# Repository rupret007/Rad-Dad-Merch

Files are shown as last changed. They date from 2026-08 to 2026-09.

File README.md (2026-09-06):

# Rad Dad Merch

Canonical home for Rad Dad physical merchandise. History imported from `rupret007/Rad-Dad-QR-Merch` at `b001fdd`. That repo stays as backup.

<p align="center"><strong>REAL DETAILS. LOUD BAND. ONE SCAN.</strong></p>

Rad Dad QR Merch turns familiar music and computer hardware into durable,
one-color punk-rock keepsakes. The collection includes an authentic micro
compact cassette, 3.5-inch floppy disk, mini VHS cassette, and the deliberately
ridiculous Trailer Swift desk collectible.

**V9 is the recommended production release.** It keeps the successful size,
keyring, and QR-fit decisions from earlier releases while restoring or deepening
the physical details that make each object immediately recognizable.

The models remain one-color prints. The interaction layer is a separate
1-inch QR sticker that opens:

```text
https://raddadband.com/qr/
```

> [!IMPORTANT]
> V9 does not enlarge the products. External envelopes, integrated keyring
> dimensions, 6 mm media-keychain bores, and the 26-27 mm protected QR landings
> stay unchanged. Authenticity improvements are contained within those proven
> boundaries.

## Start here

| I want to... | Use this |
|---|---|
| Download the complete release | [`release/v9/Rad_Dad_Retro_Riot_v9_Authenticity_QR_Print_Pack.zip`](release/v9/Rad_Dad_Retro_Riot_v9_Authenticity_QR_Print_Pack.zip) |
| Preview the current cassette, floppy, and VHS together | [Current Three digital PETG material study](docs/previews/Rad_Dad_Current_Three_PETG_Material_Study.png) |
| Browse or hold those digital studies | `python3 tools/serve_digital_merch.py` then open `/catalog` |
| Check a cart change after a connection problem | Use **Review current hold cart**; see [cart updates and recovery](docs/DIGITAL_CART.md) |
| Recover when another tab changed the cart before confirmation | Review current quantities, then confirm again; see [review-bound holds](docs/DIGITAL_HOLD_REVIEW.md) |
| Reopen or withdraw a digital hold | Open **Your holds** at `/holds` in the same browser session; see [digital holds](docs/DIGITAL_HOLDS.md) |
| Print the current cassette, floppy, and VHS together | [`release/v9/3mf/Rad_Dad_Retro_Riot_v9_CURRENT_THREE_CASSETTE_FLOPPY_VHS_A1_MINI_0.4_PROJECT.3mf`](release/v9/3mf/Rad_Dad_Retro_Riot_v9_CURRENT_THREE_CASSETTE_FLOPPY_VHS_A1_MINI_0.4_PROJECT.3mf) |
| Print the four models | [`release/v9/3mf/`](release/v9/3mf) or [`release/v9/stl/`](release/v9/stl) |
| Send one sticker to a professional vendor | `release/v9/guides/qr_stickers/Rad_Dad_QR_1IN_VENDOR_MASTER.svg` or its PDF master |
| Print precut Avery 6450 / OL1025 labels | `release/v9/guides/qr_stickers/Rad_Dad_QR_AVERY_6450_OL1025_63UP_US_LETTER.pdf` |
| Print a full adhesive sheet at FedEx Office | `release/v9/guides/qr_stickers/Rad_Dad_QR_FEDEX_OFFICE_FULL_SHEET_48UP_US_LETTER.pdf` |
| Print when black ink is unavailable | Official `Rad_Dad_QR_RED_*` fallback files in `release/v9/guides/qr_stickers/` |
| Understand sticker production | [QR sticker guide](docs/QR_STICKERS.md) |
| Review the retired NFC workflow | [NFC legacy notice](docs/NFC.md) |

The v9 ZIP is the canonical handoff. The paths above are the generated v9
release layout already present in this repository.

### Current Three material study

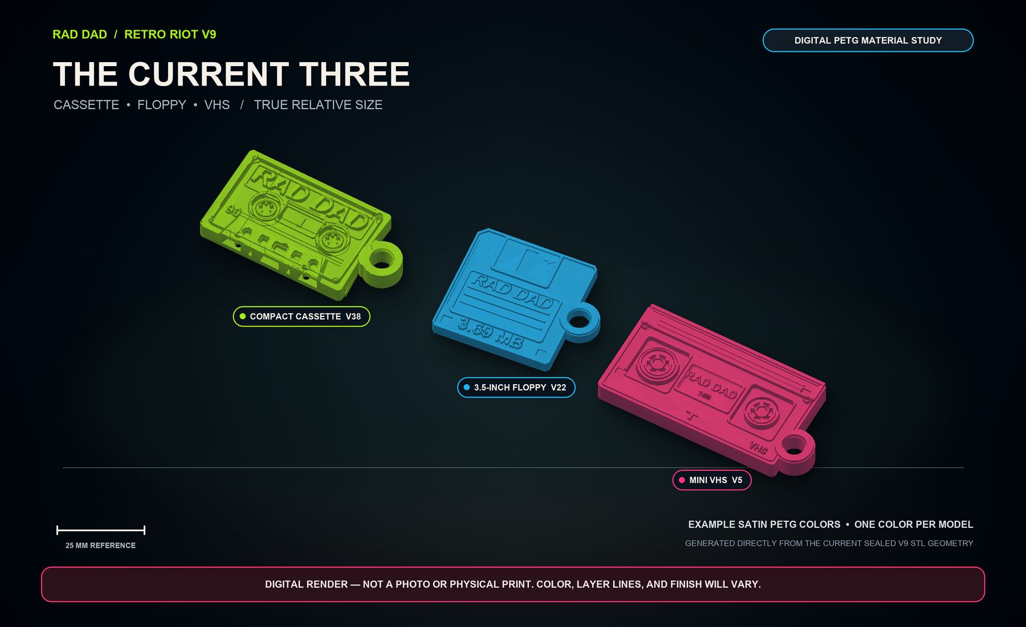
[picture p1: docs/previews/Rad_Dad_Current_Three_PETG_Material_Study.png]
Digital PETG material study of the current Rad Dad cassette, floppy, and mini VHS


This preview is generated directly from the three current sealed v9 STL files
with one shared orthographic camera, so their relative sizes remain honest.
The lime, blue, and pink surfaces are example one-color satin PETG treatments;
the image is not a photo, slicer preview, printability result, or substitute for
the physical acceptance checklist. Its source hashes, measured envelopes,
renderer identity, digital-only status, and output hash are recorded in the
[provenance file](docs/previews/Rad_Dad_Current_Three_PETG_Material_Study.json).
Regenerate or verify it with:

```bash
python3 tools/render_current_three_material_study.py
python3 tools/render_current_three_material_study.py --check
python3 tools/serve_digital_merch.py
python3 tools/verify_digital_merch.py
```

The digital merch desk turns that leftover study into a shopper catalog, cart,
and admin publish/hold path. Catalog cards crop the shared render so cassette,
floppy, and mini VHS are identifiable on a phone. Checkout cannot run until the
shopper confirms a digital hold, then it opens a session-owned receipt. It
accepts digital study requests only. It does not take payment, ship an object,
start a Bambu job, change the QR destination, or post merch. The public merch
path serves the study image and catalog copy; it does not serve STL, 3MF,
renderer, or release files. Admin stays locked until
`RAD_DAD_MERCH_ADMIN_TOKEN` is set.

**Your holds** lists this browser session's receipts, newest first. A shopper can
reopen a receipt and explicitly confirm withdrawal; the admin sees the same
withdrawn status. The original receipt stays readable. Holds live only in the
running server's memory: a server restart clears them, and clearing or losing
the session cookie removes access. See [digital holds](docs/DIGITAL_HOLDS.md)
for the flow and verification.

Cart updates show a visible result and pause further edits while pending. If a
response is lost, the browser never resends the change automatically: use
**Review current hold cart** to load the server's current quantities before
editing or requesting a hold. See [cart updates and recovery](docs/DIGITAL_CART.md).
Hold confirmation is also bound to the cart that was actually reviewed. A
changed or stale review creates no hold: the cart shows its current contents,
retains valid unsent contact/note text on that response, and requires fresh
confirmation. Empty or unavailable carts cannot submit. See
[review-bound holds](docs/DIGITAL_HOLD_REVIEW.md) for the API and recovery limits.
Digital verification uses Python 3.9+ and Node.js 18+; the JavaScript checks
use Node's standard library and require no npm packages.

## What changed in v9

### Cassette v38

Cassette v38 uses the watertight, audited v36 cassette body that produced the
successful physical reference print. Its **actual narrow tape-entry edge** is
preserved directly, including the stepped shell and asymmetric transport
apertures where a real cassette deck's head, capstan, guides, and pinch roller
engage the tape. These are not reconstructed face markings or generic slots.

Only the side-eyelet zone is moved inward to retain the later compact envelope.
The deformation is zero at the tape-entry edge, so the inherited transport
geometry remains unchanged. The proven 6 mm bore and rear QR landing are part
of the same audited body.

The shell still carries unequal tape packs, six-lobe drive hubs, center tape
window, pressure-pad cue, shell hardware, readable `RAD DAD`, `90`, and the
small `C-69` easter egg. The existing rear QR landing and compact keyring eyelet
remain unchanged.

### Floppy v22

Floppy v22 retains the developed rear hub, shutter-track, shell-seam,
write-protect, and density cues that make the underside read as a real 3.5-inch
floppy instead of a flat backing plate. The front keeps its shutter, label
hierarchy, and `RAD DAD`, while the `3.69 MB` joke is enlarged to
20.00 x 4.00 mm with heavier strokes for reliable one-color printing.

The improved marking and rear treatment stay inside the same protected 1-inch
QR landing, outside size, 4.130 mm thickness, and keyring geometry.

### VHS v5

VHS v5 strengthens the device-specific reel, tape-path, door, latch, insertion,
shell, and rear-housing cues so it reads as a VHS cassette from the front, side,
and back rather than as a stretched compact cassette.

The established rear QR landing, product envelope, and keyring geometry stay
unchanged. The restrained `T-369` detail remains part of the collection-wide
capacity joke.

### Trailer Swift v16

Trailer Swift v16 keeps the spiky punk hair, guitar, compact toy proportions,
solid display base, and readable `TRAILER SWIFT` nameplate while changing the
character's expression from angry or scary to friendly, funny, and knowingly
ridiculous. A slimmer, slightly cocked head, relaxed brows, molded eyelids and
smile creases, a broad singing grin, finished boots, and readable Strat
hardware make it a quirky collectible joke rather than a horror figure.

The 45 mm circular base and protected 27 mm QR landing beneath it stay
unchanged.

## Product specification

| Product | Revision | Unchanged external envelope | Keyring / format | V9 authenticity focus |
|---|---|---:|---|---|
| Rad Dad Compact Cassette | v38 | 58.162 x 30.260 x 6.685 mm | Integrated 6 mm bore | Exact audited narrow tape-entry edge and complete cassette transport geometry |
| Rad Dad 3.5-Inch Floppy | v22 | 44.360 x 36.916 x 4.130 mm | Integrated 6 mm bore | Authentic rear mechanics and enlarged, bold `3.69 MB` capacity mark |
| Rad Dad Mini VHS | v5 | 65.800 x 31.900 x 7.000 mm | Integrated 6 mm bore | Stronger VHS reel, tape-door, latch, insertion, and rear-device language |
| Trailer Swift | v16 | 45.000 x 45.000 x 64.400 mm | Upright desk collectible | Friendly punk caricature on a solid QR-ready display base |

| Product | Protected QR landing | Finished sticker | Radial placement clearance |
|---|---:|---:|---:|
| Cassette | 26.0 mm | 25.4 mm | 0.3 mm |
| Floppy | 26.0 mm | 25.4 mm | 0.3 mm |
| VHS | 26.0 mm | 25.4 mm | 0.3 mm |
| Trailer Swift | 27.0 mm | 25.4 mm | 0.8 mm |

## Authenticity standard

Every v9 design follows the same product rule: authentic first, branded second.

- The silhouette must identify the original object before the viewer reads the
  Rad Dad branding.
- Front, lower edge, side, and rear details must agree with the same device.
- Small features may be exaggerated enough to survive a 0.4 mm nozzle, but they
  must still represent real hardware.
- Branding may occupy label areas, but it must not replace the reels, shutters,
  transport openings, tape doors, shell seams, or other defining mechanics.
- The QR landing belongs on the rear or underside and must not flatten the
  product's authentic front.
- Durability, pocket carry, keyring access, and clean one-color printing take
  priority over fragile cosmetic detail.

## QR system

V9 removes decorative styling from the QR artwork. Preferred production uses
only pure black and pure white. The same pack includes an official pure
process-red (`#FF0000`) on white fallback, generated by the existing
`qr_artwork_v9` path, for color cartridges when black ink is unavailable:

| Property | V9 production specification |
|---|---|
| Destination | `https://raddadband.com/qr/` |
| Finished label | 25.4 mm / 1 inch round |
| QR matrix | 29 x 29 modules |
| Error correction | Q |
| Quiet zone | Four white modules on every side |
| Printed QR square | 16.5 mm; never scale smaller |
| Module pitch | Approximately 0.446 mm |
| Preferred ink | Solid black only, no gray screening |
| Official fallback ink | Pure process red `#FF0000` on white; print as color, never grayscale |
| Stock | Matte white adhesive stock |
| Individual master | Vendor-ready vector plus 600 DPI raster/PDF |
| Precut sheet | US Letter, 63-up Avery 6450 / OnlineLabels OL1025 |
| Copy-center sheet | US Letter full-sheet layout for FedEx Office cutting |
| Fallback files | `Rad_Dad_QR_RED_1IN_VENDOR_MASTER`, `Rad_Dad_QR_RED_AVERY_6450_OL1025_63UP_US_LETTER`, `Rad_Dad_QR_RED_FEDEX_OFFICE_FULL_SHEET_48UP_US_LETTER`, and `Rad_Dad_QR_RED_PRINT_CALIBRATION_US_LETTER` |

No logo, lightning bolt, text, texture, decorative color, rounded module,
transparent area, or artwork may enter the QR square or its white quiet zone.
Any surrounding label text must use the same ink as the modules. Approve the
red fallback only after the red calibration page scans from two phones.

## Printing stickers at home

1. Use matte white adhesive label stock compatible with the printer.
2. Open the PDF, not a screenshot or browser preview.
3. Select **Actual Size**, **100%**, or **No Scaling**.
4. Disable `Fit`, `Shrink oversized pages`, borderless enlargement, and photo
   optimization.
5. Print preferred black masters at the highest black-text or monochrome
   quality available. If using the official `Rad_Dad_QR_RED_` fallback, print
   as color rather than grayscale.
6. Measure a finished circle. It must be 25.4 mm across.
7. Scan samples before cutting and again after application.

Clear tape over an ordinary-paper prototype is acceptable for a fit test, but
it is not the production finish. Tape glare, bubbles, lifted edges, and adhesive
creep can reduce scan reliability. Matte white adhesive stock is the supported
batch-production material.

## FedEx Office handoff

Use the dedicated full-sheet FedEx Office PDF. Ask for:

- US Letter output.
- Actual Size / 100% with no fit-to-page scaling.
- Crisp black-only printing on matte white adhesive stock, or the official
  `Rad_Dad_QR_RED_` fallback printed as color if black ink is unavailable.
- One proof sheet before the full quantity.
- No lamination or gloss coating over the QR.

If the location cannot supply compatible matte adhesive stock, bring laser-safe
full-sheet matte white label paper and confirm that the store accepts customer
stock before ordering. Measure and scan the proof while still at the counter.

## Mandatory physical scan QC

Digital generation does not prove that a printed sticker scans. Every batch
must pass physical quality control:

1. Print the calibration page at Actual Size / 100%.
2. Confirm the 25.4 mm circle and any dimensional reference with a ruler or
   caliper.
3. Check that modules are square, solid, separated, and surrounded by an intact
   white quiet zone.
4. Scan labels from the top, center, and bottom of every printed sheet.
5. Verify that every sample opens exactly `https://raddadband.com/qr/`.
6. Apply stickers only to clean, dry, flat landings.
7. Scan every finished product with at least one current iPhone and Android
   phone.
8. Repeat scans under ordinary indoor lighting and from more than one approach
   angle.
9. Allow the adhesive to cure for 24 hours, perform carry and handling checks,
   and scan again.
10. Do not distribute any piece that scans slowly, inconsistently, or to the
    wrong destination.

## Model printing baseline

| Setting | Media keychains | Trailer Swift |
|---|---|---|
| Printer | Bambu Lab A1 Mini | Bambu Lab A1 Mini |
| Nozzle | 0.4 mm | 0.4 mm |
| Layer height | 0.16 mm | 0.16 mm |
| Initial layer | 0.20 mm | 0.20 mm |
| Walls | 4 | 4 |
| Top / bottom layers | 5 / 5 | 5 / 5 |
| Infill | 30% gyroid | 30% gyroid |
| Wall generator | Arachne | Arachne |
| Supports | Off | Organic/tree, build plate only |
| Orientation | Detailed face upward | Upright on circular base |

Use an explicitly named `_A1_MINI_0.4_PROJECT.3mf` for embedded Bambu settings.
Use a `_MODEL_ONLY.3mf` or binary STL when choosing a custom profile. Inspect
the sliced preview before committing material.

## Release lineage

| Release | Status | Purpose |
|---|---|---|
| [`release/v9`](release/v9) | **Recommended** | Authenticity-restored models and production black-and-white QR system |
| [`release/v8`](release/v8) | Superseded | First QR-first release; reused v7 geometry unchanged |
| [`release/v7`](release/v7) | Legacy archive | Final NFC-oriented micro-replica release |

NFC remains documented for historical reference, but it is not part of the v9
production workflow. Existing v7 and v8 prints can still use the v9 25.4 mm QR
sticker because the landing dimensions did not change.

## Repository map

| Path | Purpose |
|---|---|
| `release/v9/` | Recommended Authenticity + QR release |
| `release/v8/` | Historical first QR release |
| `release/v7/` | Historical NFC release |
| `src/digital_merch/` | Digital merch desk: catalog, cart, admin, public-path security |
| `docs/QR_STICKERS.md` | QR artwork, printing, installation, and physical QC |
| `docs/NFC.md` | Legacy NFC retirement notice |
| `CHANGELOG.md` | Release history and revision details |

## Safety and scope

These are promotional keepsakes, not safety equipment. Eyelets are not rated
for climbing, restraint, lifting, or protecting valuables. Small parts and
split rings may present hazards to children. Follow printer, filament, adhesive,
cutting-tool, and copy-center safety guidance.

See [LICENSE.md](LICENSE.md) and [THIRD_PARTY_NOTICES.md](THIRD_PARTY_NOTICES.md)
for licensing and attribution details.

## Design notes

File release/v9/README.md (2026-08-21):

# Rad Dad Retro Riot v9: Authenticity + QR Edition

**AUTHENTIC LITTLE OBJECTS. LOUD BAND. ONE EASY SCAN.**

This release restores the physical cues that make the cassette, floppy disk,
and VHS recognizable while keeping the Trailer Swift collectible funny rather
than frightening. Every exterior envelope and attachment opening remains the
same size as v7. The NFC workflow is replaced by a visible, black-and-white,
one-inch QR sticker that opens `https://raddadband.com/qr/`.

## Start here

| Need | File |
|---|---|
| Print the current cassette, v22 floppy, and VHS together | `3mf/Rad_Dad_Retro_Riot_v9_CURRENT_THREE_CASSETTE_FLOPPY_VHS_A1_MINI_0.4_PROJECT.3mf` |
| Print all four together | `3mf/Rad_Dad_Retro_Riot_v9_ALL_FOUR_MODEL_ONLY.3mf` |
| Print all four with Trailer Swift supports preset | `3mf/Rad_Dad_Retro_Riot_v9_ALL_FOUR_A1_MINI_0.4_TREE_SUPPORT_PROJECT.3mf` |
| Print on 63-up pre-cut stock | [Rad_Dad_QR_AVERY_6450_OL1025_63UP_US_LETTER.pdf](guides/qr_stickers/Rad_Dad_QR_AVERY_6450_OL1025_63UP_US_LETTER.pdf) |
| Print at FedEx Office on adhesive paper | [Rad_Dad_QR_FEDEX_OFFICE_FULL_SHEET_48UP_US_LETTER.pdf](guides/qr_stickers/Rad_Dad_QR_FEDEX_OFFICE_FULL_SHEET_48UP_US_LETTER.pdf) |
| Send one design to a sticker vendor | [Rad_Dad_QR_1IN_VENDOR_MASTER.pdf](guides/qr_stickers/Rad_Dad_QR_1IN_VENDOR_MASTER.pdf) |
| Check printer scaling first | [Rad_Dad_QR_PRINT_CALIBRATION_US_LETTER.pdf](guides/qr_stickers/Rad_Dad_QR_PRINT_CALIBRATION_US_LETTER.pdf) |
| Print without black ink, using pure red | [Rad_Dad_QR_RED_AVERY_6450_OL1025_63UP_US_LETTER.pdf](guides/qr_stickers/Rad_Dad_QR_RED_AVERY_6450_OL1025_63UP_US_LETTER.pdf) |
| Print a red full sheet for hand cutting | [Rad_Dad_QR_RED_FEDEX_OFFICE_FULL_SHEET_48UP_US_LETTER.pdf](guides/qr_stickers/Rad_Dad_QR_RED_FEDEX_OFFICE_FULL_SHEET_48UP_US_LETTER.pdf) |
| Send the red master to a vendor | [Rad_Dad_QR_RED_1IN_VENDOR_MASTER.pdf](guides/qr_stickers/Rad_Dad_QR_RED_1IN_VENDOR_MASTER.pdf) |
| Calibrate and scan-test red first | [Rad_Dad_QR_RED_PRINT_CALIBRATION_US_LETTER.pdf](guides/qr_stickers/Rad_Dad_QR_RED_PRINT_CALIBRATION_US_LETTER.pdf) |
| Follow the physical acceptance gate | [Physical QC checklist](qa/PHYSICAL_QC_CHECKLIST.md) |

## V9 authenticity changes

- Cassette: five real lower-edge transport bays align with the five front
  transport positions. A continuous rear skin and substantial ribs retain
  keychain durability without restoring the previous solid toy-like edge.
- Floppy: rear spindle, shutter-track, shell-seam, and write-protect cues frame
  the functional QR landing; the front keeps `RAD DAD` and rebuilds `3.69 MB`
  at 20.00 x 4.00 mm with heavier strokes for reliable 0.4 mm-nozzle printing.
- VHS: rear reel-drive, shell, door, and fastener cues join the front tape door,
  windows, hubs, `RAD DAD`, and `T-369` details.
- Trailer Swift: the stable solid base and underside QR landing remain, while
  a slimmer cocked head, layered facial structure, a broad singing grin,
  finished boots, and molded Strat hardware make the character quirky rather
  than angry.

## QR specification

- Finished sticker: 25.4 mm / 1.000 inch round
- QR field: 16.5 mm, black modules on pure white
- Matrix: 29 x 29 modules with error correction Q
- Quiet zone: four complete modules on every side
- Module pitch: approximately 0.446 mm
- Standard artwork: pure black on white
- Color-cartridge fallback: pure process red `#FF0000` on white
- Artwork: vector plus lossless 600 DPI raster/PDF production files
- Print scaling: Actual Size / 100%; never Fit or Scale to Page

Black remains the preferred production color. Use the red files when black ink
is unavailable, select color printing rather than grayscale, and approve them
only after the red calibration code scans from two phones.

## Physical-production rule

Print one of each model and one ordinary-paper QR proof before producing a
batch. A finished item passes only when the installed QR opens the Rad Dad QR
page with the normal camera on both iPhone and Android in indoor and outdoor
light. The digital files cannot substitute for a physical print and scan test.

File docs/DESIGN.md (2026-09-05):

# Rad Dad Retro Riot v9 design specification

## Product intent

The collection turns recognizable music-media hardware into durable,
single-color punk-rock keepsakes. Each object must read as its real-world
inspiration before the viewer notices the Rad Dad branding or capacity joke.
The models are designed at 100% scale for a Bambu Lab A1 mini with a 0.4 mm
nozzle. Do not scale them to solve text, eyelet, or sticker-fit problems.

## Current production models

| Product | Revision | Exact envelope | Use | Keyring bore | QR landing |
|---|---:|---:|---|---:|---:|
| Compact cassette | v38 | 58.162 x 30.260 x 6.685 mm | Keychain | 6.0 mm | 26.0 mm rear |
| 3.5-inch floppy | v22 | 44.360 x 36.916 x 4.130 mm | Keychain | 6.0 mm | 26.0 mm rear |
| Mini VHS | v5 | 65.800 x 31.900 x 7.000 mm | Keychain | 6.0 mm | 26.0 mm rear |
| Trailer Swift | v16 | 45.000 x 45.000 x 64.400 mm | Desk collectible | None | 27.0 mm underside |

The cassette, floppy, and VHS eyelets use two-sided lead-ins around a nominal
6.0 mm cylindrical opening. The reinforced neck must remain thick enough for
split-ring installation and normal key carry. The media products print flat
with their detailed faces up. Trailer Swift prints upright with tree support.

### Current Three preview truth

`docs/previews/Rad_Dad_Current_Three_PETG_Material_Study.png` is the dedicated
visual overview for the current cassette v38, floppy v22, and mini VHS v5. The
renderer reads their checked-in v9 binary STL files directly and uses a shared
orthographic camera so the relative scale is not editorially distorted. The
three colors visualize separate one-color satin PETG prints; they do not claim
an exact filament, surface finish, layer result, or successful physical print.

The adjacent JSON records the three source hashes and measured envelopes, the
renderer hash, the output hash, and `physical_proof: false`. CI checks all of
that provenance and performs a disposable smoke render. The study does not
change, regenerate, or validate any STL, 3MF, Bambu profile, release archive,
QR artwork, or physical acceptance step.

The digital merch desk in `src/digital_merch/` uses that leftover study as the
only public catalog source. Shoppers can view published digital study cards,
tell cassette, floppy, and mini VHS apart by cropped study windows, add them to
a hold cart, and request a hold. A confirmed request opens a session-owned
receipt; other sessions cannot read it. Admin can publish or unpublish those
cards. The public merch path is an allowlist: it can serve the study image,
catalog copy, and hold receipts, not source hashes, STL paths, 3MF projects, or
the renderer. Checkout rejects shipping, payment, printer, and social-post
fields and requires an explicit digital-hold confirmation. This desk is not a
second QR destination and it does not prove a physical print.

## Shared design hierarchy

Every media replica follows the same priority order:

1. Recognizable device silhouette and device-specific mechanical hardware.
2. Durable shell, eyelet, and protected sticker landing.
3. Readable `RAD DAD` branding.
4. A restrained `369` capacity-format joke.
5. Fine molded seams, screws, tracks, and registration cues.

Branding must never replace the hardware that identifies the object. Raised
features must be positively joined to the shell, and recessed details must not
break through a sticker landing or structural skin.

## Compact cassette v38

The cassette uses the audited v36 body that produced the successful physical
reference print. V38 moves only the eyelet zone inward while preserving the
complete lower transport edge.

Required recognition cues:

- Unequal tape packs and two six-lobe reel-drive hubs.
- Central tape window and pressure-pad cue.
- Raised `RAD DAD`, `90`, and the small `C-69` easter egg.
- Molded perimeter, screw, and label geometry.
- Five open lower-edge transport bays aligned with the front transport path.
- Stepped, asymmetric head, capstan, guide, and pinch-roller openings.

The transport edge is intentionally real geometry, not decorative rectangles
on the front face. It must remain open and visible from the physical bottom of
the printed cassette. The rear stays continuous for durability and QR sticker
adhesion.

## 3.5-inch floppy v22

Required recognition cues:

- Nearly square shell with asymmetric orientation chamfer.
- Top shutter panel, shutter fold, and protected head-slot impression.
- Asymmetric lower-corner write-protect and density-detection shell recesses.
- Writable front label with raised `RAD DAD` and three ruled lines.
- Centered, high-contrast `3.69 MB` capacity mark.
- Rear spindle witness ring, radial ribs, shutter tracks, shell seam, and
  write-protect treatment around the QR landing.

The physical v20 print showed that the original 10.20 x 2.30 mm capacity mark
was too difficult to read. V22 uses a 20.00 x 4.00 mm bold mark centered in the
clear shell field directly below the writable label. It is built into the original Boolean assembly,
not stacked onto a finished mesh. Its top remains at the established 4.130 mm
maximum, so the improvement does not increase the product envelope.

## Mini VHS v5

Required recognition cues:

- Wide VHS proportions that cannot be confused with an audio cassette.
- Full-width tape-door treatment and independent reel windows.
- Asymmetric tape packs with six-rib reel hubs.
- Central label with large, readable `RAD DAD` branding.
- `VHS` identity mark and restrained `T-369` running-time joke.
- Rear reel-drive rings, loading-door tracks, shell seam, screws, latch, and
  write-protect cues.

The rear cues surround the protected circular sticker landing. They must not
reduce adhesive contact or open through the shell.

## Trailer Swift v16

Trailer Swift is a funny, friendly punk-rock micro-collectible inspired by the
album persona, not a realistic portrait and not a frightening caricature.

Required cues:

- Slim, slightly cocked stylized head with layered eyelids, smile creases,
  broad singing expression, inner-ear detail, and energetic punk hair.
- Strat-style guitar with double cutaways, three pickups, pole pieces,
  pickguard fasteners, tremolo hardware, controls, and six-inline tuners.
- Stage stance, clean jeans, laced boots, and readable `TRAILER SWIFT` nameplate.
- Solid circular display base that supports the figure like a compact toy.
- Protected 27.0 mm underside landing for the 25.4 mm QR sticker.

The base, feet, neck, guitar, hair, and hands must form one connected,
watertight body. Supports must be removable without breaking the character.

## QR interaction standard

The current production interaction is a visible 25.4 mm / 1-inch matte-white
sticker. Preferred artwork is a solid-black QR. The official fallback, when
black ink is unavailable, is pure process red `#FF0000` on white from the
existing `Rad_Dad_QR_RED_` files. NFC hardware is not installed.

- Canonical destination: `https://raddadband.com/qr/`
- Legacy ordered stickers using `/tap/` remain valid through a permanent
  website redirect.
- QR matrix: 29 x 29 modules, error correction Q.
- Quiet zone: four complete white modules on all sides.
- QR field: 16.5 mm square inside the 25.4 mm circular sticker.
- Media landing: 26.0 mm minimum protected diameter.
- Trailer Swift landing: 27.0 mm protected diameter.

The sticker belongs on the rear or underside landing only. It must not cover
the device-defining front details or any keyring opening. Use no metallic,
holographic, transparent, dark, or reflective stock.

## Digital and physical acceptance

Digital acceptance requires one connected watertight body, zero boundary,
non-manifold, and degenerate edges, consistent winding, exact envelope, and fit
inside the 180 mm A1 Mini volume. Physical acceptance additionally requires a
sliced Preview review, one proof print, dimensional checks, text readability,
split-ring installation, drop/carry testing, sticker adhesion, and camera scans
on iPhone and Android. See [VALIDATION.md](VALIDATION.md).

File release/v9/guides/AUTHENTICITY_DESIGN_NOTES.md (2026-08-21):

# V9 authenticity design notes

The visual hierarchy is intentional: each item must read as its real-world
reference before the viewer notices the Rad Dad branding or QR function.

The cassette transport features are open to the top/edge rather than capped by
hidden bridge ceilings. The retained rear skin is divisible into ordinary
0.20 mm layers, and the ribs between transport bays carry edge loads.

The floppy and VHS rear details use shallow engravings outside the QR quiet
landing. They should survive ordinary slicing without making the rear surface
rock on the bed. The QR sticker remains centered and fully supported.

Trailer Swift remains a one-piece desk collectible. Friendly facial changes
avoid thin standalone parts and preserve the support strategy and stable base.

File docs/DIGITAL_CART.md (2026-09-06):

# Digital cart updates and recovery

An added study or quantity change is a digital cart edit. It does not create a
hold, payment, print job, shipment, or message.

## Review the outcome

With JavaScript available, the desk shows **Updating your hold cart** and pauses
other cart edits and hold submission until the response arrives. Successful
catalog edits update the cart count. Successful edits on `/cart` or `/checkout`
load the current cart so displayed quantities match the server.

A rejected edit, such as exceeding three of one study, shows a visible error
and restores the available controls. The quantity buttons keep the exact value
the shopper selected. Buttons that were already disabled remain disabled.

If the connection fails, the response cannot be read, or the response takes
longer than ten seconds, the desk cannot confirm whether the change happened.
It does not resend the change. Cart edits and hold submission remain paused.
Choose **Review current hold cart** to load the current session's cart, inspect
its quantities, then decide what to do next. That link only reads the cart.
If the connection is still unavailable, return to that link when it recovers.

The status is visible and announced to assistive technology. Errors and
uncertain results move keyboard focus to the status and its recovery link.
Without JavaScript or the required browser APIs, ordinary form navigation
continues to work with the pressed quantity button's value.

## Scope and verification

This prevents automatic retry of an uncertain cart POST in the current page.
It does not make every cart edit transactional across tabs or make the
server's in-memory session durable. Final hold creation additionally uses a
[review-bound confirmation](DIGITAL_HOLD_REVIEW.md): another tab's changed cart
or a reused old form cannot silently create an unreviewed hold. Receipt history
and withdrawal are unchanged.

Run `python3 tools/verify_digital_merch.py` with Python 3.9+ and Node.js 18+.
The verifier includes the existing shopper/admin/session/security tests and
dependency-free JavaScript transport tests. Browser verification uses a local
synthetic session and can drop a response after the server applies the edit,
checking that review shows the actual quantity without another POST.

Physical release files, study assets and provenance, QR destination, provider
boundaries, and publication controls are unchanged.

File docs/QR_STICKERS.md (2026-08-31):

# V9 QR sticker production

## Production decision

Rad Dad Retro Riot v9 uses one visible 25.4 mm / 1-inch QR sticker as the
supported handoff mechanism. The models remain durable one-color prints; the
separate label provides the contrast a camera needs without an AMS, filament
change, or unreliable shadow-based 3D code.

Preferred production is pure black modules on matte white. The same v9 pack
also ships an official pure process-red (`#FF0000`) on white fallback, generated
by the existing `qr_artwork_v9` path, for printers that are out of black ink.
That fallback is not a second destination, a decorative color treatment, or a
second merch app.

NFC is now a legacy experiment, not a production dependency.

## Permanent destination

```text
https://raddadband.com/qr/
```

The code is static and the route is controlled by Rad Dad. Update shows, music,
videos, and campaigns on the landing page instead of replacing distributed
stickers.

## Fit across all four products

V9 deepens authentic device details without changing the proven sticker fit:

| Product | Model revision | Protected landing | Sticker | Radial clearance |
|---|---|---:|---:|---:|
| Compact cassette | v38 | 26.0 mm | 25.4 mm | 0.3 mm |
| 3.5-inch floppy | v22 | 26.0 mm | 25.4 mm | 0.3 mm |
| Mini VHS | v5 | 26.0 mm | 25.4 mm | 0.3 mm |
| Trailer Swift | v16 | 27.0 mm | 25.4 mm | 0.8 mm |

Cassette v38 directly preserves the audited narrow tape-entry edge from the
successful earlier body, including its stepped shell and asymmetric transport
apertures. Floppy v22 retains its developed rear cues and adds a larger,
heavier `3.69 MB` front capacity mark. VHS v5 deepens its rear and
device-specific cues around, not through, the unchanged QR landing. Trailer
Swift v16 retains the protected pocket beneath the solid circular base.

## Non-negotiable artwork rules

Preferred black masters:

- Use pure black modules on a solid white field.
- Use no gray, tint, gradient, texture, transparency, or decorative color.
- Keep any `RAD DAD` or `SCAN ME` wording outside the protected QR field and
  render it in the same ink as the modules.

Official red fallback, only when black ink is unavailable:

- Use the supplied `Rad_Dad_QR_RED_` files. Do not pick a different red.
- Modules and cut guides are pure process red `#FF0000` on solid white.
- Print as color, never grayscale or a printer-selected red.
- Approve only after the red calibration page scans from two phones.

Shared rules for both colors:

- Preserve a four-module white quiet zone on every side.
- Keep the printed QR square at 16.5 mm. Never make it smaller.
- Keep every module square, crisp, separated, and approximately 0.446 mm wide.
- Put no logo, lightning bolt, text, border, or artwork inside the QR square or
  quiet zone.
- Do not round, invert, distress, stylize, or partially cover modules.
- Use matte white adhesive stock to reduce glare.

The QR is intentionally plain. At this physical size, scan reliability is more
important than decorative customization.

## Generated production files

The completed v9 pack is generated at:

```text
release/v9/Rad_Dad_Retro_Riot_v9_Authenticity_QR_Print_Pack.zip
```

The pack includes three print layouts. A layout proves geometry, not adhesive
durability; qualify the stock separately before installing a label on a
finished piece.

| Route | Preferred black file | Official red fallback |
|---|---|---|
| Individual vendor | `Rad_Dad_QR_1IN_VENDOR_MASTER.svg`, PNG, and PDF | `Rad_Dad_QR_RED_1IN_VENDOR_MASTER.svg`, PNG, and PDF |
| Precut 63-up geometry | `Rad_Dad_QR_AVERY_6450_OL1025_63UP_US_LETTER.pdf` | `Rad_Dad_QR_RED_AVERY_6450_OL1025_63UP_US_LETTER.pdf` |
| FedEx Office full sheet | `Rad_Dad_QR_FEDEX_OFFICE_FULL_SHEET_48UP_US_LETTER.pdf` | `Rad_Dad_QR_RED_FEDEX_OFFICE_FULL_SHEET_48UP_US_LETTER.pdf` |
| Calibration | `Rad_Dad_QR_PRINT_CALIBRATION_US_LETTER.pdf` | `Rad_Dad_QR_RED_PRINT_CALIBRATION_US_LETTER.pdf` |

The release also includes a placement guide and physical QC checklist. Send a
vendor the SVG or PDF master, never a screenshot. Black remains the preferred
production color. Use the red files only when black ink is unavailable.

Avery 6450 is removable-adhesive proof-only matte paper. Every giveaway,
keychain, or carry-production piece requires permanent adhesive. Use the same
63-up geometry for a finished piece only with a documented permanent,
weatherproof matte-white OL1025-compatible material, or have the individual
master professionally printed on permanent matte-white vinyl. Confirm the
actual material and adhesive specification before printing: layout compatibility
does not make removable stock permanent.

## Home-printer workflow

1. Confirm that the label stock matches the printer technology.
2. Choose stock for the job. Avery 6450 removable labels are proof-only; an
   installed or carried piece requires permanent, weatherproof matte-white
   stock.
3. Print the calibration page on ordinary paper first.
4. Open the supplied PDF in a PDF reader.
5. Choose **Actual Size**, **100%**, or **No Scaling**.
6. Disable fit-to-page, shrink, enlargement, borderless scaling, and photo
   enhancement.
7. Select the highest available monochrome or black-text quality for preferred
   black masters. If printing a `Rad_Dad_QR_RED_` file, select color rather
   than grayscale.
8. Print one proof and let the ink or toner settle completely.
9. Measure the 25.4 mm circle and the calibration reference.
10. Scan the proof before committing sticker stock.

The 63-up file is only for the specified precut geometry. Avery 6450 may prove
alignment and scanning, but its removable adhesive is not production stock.
Use a permanent, weatherproof OL1025-compatible material for finished pieces,
or use the dedicated full-sheet file for uncut permanent adhesive stock.

## FedEx Office workflow

Provide the dedicated FedEx Office full-sheet PDF and these written
instructions:

```text
Print US Letter at Actual Size / 100%.
Do not fit, shrink, enlarge, crop, or use borderless scaling.
Print solid black on matte white adhesive stock.
If black ink is unavailable, use the official Rad_Dad_QR_RED_ full-sheet file
and print as color, not grayscale.
Do not laminate or apply a gloss coating.
Produce one proof sheet before the full order.
```

Ask the associate to confirm the final stock before printing. If the location
does not carry matte white full-sheet adhesive material, ask whether it accepts
customer-supplied laser-safe label stock. Do not substitute glossy photo paper,
clear labels, metallic stock, colored stock, or textured material.

Before leaving the counter:

1. Measure one finished 25.4 mm circle.
2. Scan QR codes from the top, center, and bottom of the proof sheet.
3. Confirm that each opens exactly `https://raddadband.com/qr/`.
4. Reject scaling, clipped circles, broken modules, banding, weak black, or
   excessive toner shine.

## Cutting and installation

1. Scan the sheet before cutting.
2. Cut on the circular guide without entering the white QR quiet zone.
3. Inspect the model landing for ridges, loose filament, oil, or dust.
4. Clean the landing with 70% isopropyl alcohol and let it dry completely.
5. Center the sticker inside the registration landing without stretching it.
6. Press from the center outward to avoid wrinkles or bubbles.
7. Hold firm pressure for 30 seconds.
8. Scan immediately after installation.
9. Let the adhesive cure for 24 hours.
10. Carry-test the finished item and scan again.

| Product | Sticker location |
|---|---|
| Cassette | Centered on the protected flat rear landing |
| Floppy | Centered inside the rear faux-hub registration ring |
| VHS | Centered inside the rear registration ring |
| Trailer Swift | Centered inside the pocket beneath the circular base |

## Mandatory physical scan QC

A valid digital QR does not guarantee a valid physical sticker. Every
production batch must pass all of the following:

- The finished circle measures 25.4 mm.
- The QR square remains 16.5 mm and the quiet zone is intact.
- Black modules are dense, square, and free of gaps or toner flaking. If using
  the official red fallback, modules are solid `#FF0000` with no gray or mixed
  red, and the red calibration page has already scanned from two phones.
- White areas are clean and free of background pattern or adhesive show-through.
- Top, center, and bottom sheet samples scan before cutting.
- Every installed product scans after application.
- Finished pieces scan on at least one current iPhone and Android phone.
- Scans succeed in normal indoor light and from multiple approach angles.
- Every scan resolves to `https://raddadband.com/qr/`.
- Finished pieces still scan after 24-hour cure and carry testing.

Quarantine and replace any label that scans slowly or inconsistently. Do not
assume another person's phone will compensate for a marginal print.

## Material recommendations

| Stage | Stock | Notes |
|---|---|---|
| Fit proof | Ordinary white paper | Confirm size and scan behavior before using adhesive stock |
| Precut proof | Avery 6450 removable matte-white paper labels | Confirm 63-up alignment and scanning only; do not install on a carry piece |
| Home prototype | Matte white full-sheet adhesive paper | Protect only after scanning; clear tape is a temporary proof method |
| Home batch | Weatherproof matte white adhesive stock | Better abrasion and moisture resistance with lower glare |
| Production batch | Professionally printed matte white vinyl | Request crisp black output, permanent adhesive, and a physical proof |

Clear tape may protect an ordinary-paper prototype, but it can introduce glare,
bubbles, edge lift, and adhesive creep. It is not the recommended finish for
giveaways or keychain carry.

## Release compatibility

V9 is the recommended release. Existing v7 NFC-era and v8 QR-era prints can use
the v9 sticker artwork because their 26-27 mm interaction landings share the
same 25.4 mm label fit. They do not gain the v9 authenticity improvements unless
the models themselves are reprinted.

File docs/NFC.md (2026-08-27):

# NFC workflow: legacy archive

NFC is not part of the recommended Rad Dad Retro Riot v9 production workflow.
V9 uses a visible 25.4 mm / 1-inch QR sticker that a recipient can recognize
and scan with the normal phone camera. Preferred production is pure black on
white; the v9 pack also includes an official process-red fallback when black
ink is unavailable.

## Why NFC became legacy

Real-world testing exposed too many dependencies for a giveaway or keychain
product:

- Chip provenance and inconsistent tag quality.
- Correct NDEF formatting and write completion.
- Differences in iPhone and Android background scanning.
- Antenna coupling, phone position, and installation tolerance.
- Potential interference from nearby material or hardware.
- A second overlay or instruction needed to explain where to tap.

The QR workflow makes the action visible, removes programming, and allows every
finished piece to be tested with the same camera behavior the recipient will
use.

## Historical releases

The final NFC-oriented release remains available under
[`release/v7`](../release/v7) for reference and experimentation. The first
QR-first transition remains under [`release/v8`](../release/v8).

Do not use the v7 NFC instructions as the current batch-production procedure.
V9 is the recommended release and its generated pack is:

```text
release/v9/Rad_Dad_Retro_Riot_v9_Authenticity_QR_Print_Pack.zip
```

The supported sticker process is documented in
[QR_STICKERS.md](QR_STICKERS.md).

## Compatibility with existing prints

Existing v7 and v8 prints do not need to be discarded. Their protected 26-27 mm
interaction landings accept the v9 25.4 mm QR sticker directly.

The v9 models are still recommended for new prints because they add the latest
authenticity work:

- Cassette v38 directly preserves the audited narrow tape-entry edge and its
  asymmetric real-cassette transport apertures.
- Floppy v22 retains the rear device cues and adds a more readable front
  `3.69 MB` capacity mark without changing the QR landing or outer envelope.
- VHS v5 deepens rear and VHS-specific cues around the same QR landing.
- Trailer Swift v16 uses a friendly, funny expression while retaining the same
  QR-ready base envelope.

External envelopes and media-keychain dimensions remain unchanged. The v9
upgrade improves recognizability without increasing the products' size.

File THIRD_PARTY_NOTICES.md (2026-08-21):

# Third-party notices and public-release hold

This repository is intentionally private.

## Cassette source

The cassette started from the user-supplied MakerWorld model **Mini Cassette
Tape Keychain with NFC Tag** by Jon Otero, MakerWorld model 1061187. The source
was supplied under MakerWorld's Standard Digital File License. Keep derivative
geometry private unless written redistribution permission is obtained.

## Floppy source

The floppy started from the user-supplied file `Floppy+Disk+3_5.3mf`. Confirm
the original creator, source page, and redistribution terms before any public
release. Until that review is complete, keep derivative geometry private.

## Original work

The Rad Dad branding, Trailer Swift character interpretation, revised NFC and
keyring engineering, VHS geometry, documentation, and build system are project
work created for Rad Dad. The album artwork used as a visual reference is not
embedded in the printable mesh.

## Rule before changing visibility

Do not make this repository public and do not publish downloadable 3MF, STL,
or ZIP files until both third-party reviews are documented in writing.

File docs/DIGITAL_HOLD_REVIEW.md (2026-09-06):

# Hold exactly the studies you reviewed

The digital merch desk now binds each hold confirmation to the session's
reviewed studies, quantities, cart revision and current catalog details. A
different tab cannot silently substitute a study or change the requested
quantity between review and checkout. An old successful form also cannot
create another hold after an identical cart is refilled.

## Shopper recovery

If the review is missing or out of date, no hold is created and the cart is not
cleared. The existing cart page shows its current contents and a fresh-review
message. Valid optional contact and note text is retained safely on that page;
the confirmation checkbox is reset. Read the current studies and quantities,
then explicitly confirm again if they are right. There is no automatic retry.

If the cart is now empty or contains an unavailable study, checkout is absent.
Unavailable lines remain identifiable and removable. Unsent details stay
visible with an instruction to copy them before leaving the page. They are
not a saved draft: subsequent cart edits, reloads or navigation can discard
them. The existing hold history and withdrawal flow is unchanged.

Native HTML forms work without JavaScript. The cart-update enhancement and
its uncertain-response recovery remain as described in [DIGITAL_CART.md](DIGITAL_CART.md).

## API and security contract

1. Read `/api/cart` and show its `items` to the shopper. Retain the accompanying
   `checkout_review` for that displayed snapshot.
2. Submit that exact field to `/api/checkout` along with the existing valid
   session/CSRF and explicit `confirm_digital_hold` value. Do not fetch a new
   review silently just to submit an old display.
3. HTTP `409` with `code: cart_review_required` means no hold was created.
   `review_path: /cart` is a read-only recovery destination. Show current items
   and require fresh confirmation; do not automatically replay the request.
4. Existing invalid confirmation/eligibility failures remain `400`; CSRF,
   forbidden fields, oversized forms and other security failures remain `403`.
   A valid review never overrides eligibility or authorizes payment/printing.

The opaque review is a purpose-bound HMAC over the session identity, monotonic
cart revision and sorted item/catalog snapshot. It contains no contact/note
text. Successful cart changes and checkout clearing advance the revision;
ordinary reads and rejected mutations do not. All WSGI requests in the current
process share a lock, covering rendered rows/token and checkout validation,
request creation and cart clearing. This is not a multi-worker transaction,
persistent reservation, durable session, payment or fulfillment system.

## Evidence and handoff

Three real-WSGI regressions on unchanged main `fc73aa38` demonstrated an
unreviewed quantity, a different study, and a duplicate hold after refill.
The new review/security tests cover these cases, foreign/tampered/missing
reviews, metadata and availability changes, concurrent submissions, literal
text preservation, native/API success and existing security boundaries.

Run `python3 tools/verify_digital_merch.py` with the existing dependencies.
It includes the Python product/security tests and the unchanged 30-case Node
cart-transport suite. Browser proof exercises synthetic two-tab journeys at
320/390/1280 pixels with JavaScript both enabled and disabled. Exact tested
tip, actual final counts and hosted-run receipts belong in the draft PR and
coordination AFTER; do not infer deployment or physical proof from these tests.

No dependency, workflow, physical generator, sealed study/model/release asset,
QR destination or live service changes. Parked #2 stays untouched. One OPEN
DRAFT for Karen leftover + security; no merge, release, Pages, purchase, print,
post, send or credential action from this slice.

Made-with: Codex Astra Ultra

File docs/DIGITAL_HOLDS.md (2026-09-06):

# Digital holds

The digital merch desk lets a shopper hold a study for admin review. A hold
does not reserve a physical item or create a purchase, print, shipment, or
message.

## Find and withdraw a hold

1. Start `python3 tools/serve_digital_merch.py`, open the local `/catalog`, add a
   digital study to the cart, and explicitly confirm the digital hold at checkout.
2. Open **Your holds** from navigation to find this browser session's receipts,
   newest first. Each entry shows the study names, quantities, requested time,
   and status; contact information and notes appear only on its receipt.
3. Open a receipt. To withdraw it, check the confirmation and select
   **Withdraw digital hold**. The receipt and admin desk show **Withdrawn** and
   the receipt records the withdrawal time in UTC.

Withdrawal stops that request from waiting for admin review. It preserves the
receipt ID, study quantities, original request time, contact information, and
note. Retrying the withdrawal leaves the first withdrawal time intact. It does
not change the cart or catalog. To request a study again, create a new hold.
The complete flow works without JavaScript.

## Session limits

Holds and sessions are stored in the running server's memory. Restarting the
server clears them. Access requires the same session cookie; clearing it,
losing it, or using another browser removes access to those receipts. This is
temporary session history, not durable order history or a data-erasure feature.

Only the owning session can view or withdraw its receipt. An admin can review
all requests but does not gain permission to withdraw another session's hold.
Withdrawal requires a POST, the current session's CSRF token, and explicit
confirmation. Missing and foreign receipts use the same not-found response.
The public route allowlist still excludes physical release and generator files.

## Verification

```bash
python3 tools/verify_digital_merch.py
```

The verifier covers receipt creation, history ordering and isolation, confirmed
withdrawal, request-method and CSRF rejection, repeat submissions, catalog
unpublication, retained cart and receipt details, admin status, HTML escaping,
and lost-session/server-restart behavior. Existing release-integrity checks
continue to verify the sealed physical files and material-study provenance.

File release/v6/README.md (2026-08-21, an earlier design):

# Rad Dad Retro Riot v6

**Old media. Loud band. One tap.**

## Print first

Use the individual `SINGLE_TEST` 3MF files before the combined plate. The media pieces print flat without supports. Trailer Swift is an upright desk collectible and needs organic supports from the build plate.

## What changed

- VHS v3 now has a dominant hinged tape door, framed reel bay, authentic hubs, center gauge, five screws, and compact label.
- Floppy v18 restores rear shell hardware without reducing the 25 mm NFC contact area.
- Trailer Swift v4 is a solid-base collectible with toy-like depth, a faux bobble spring, front nameplate, and underside NFC placement.
- Cassette v36 remains unchanged because its current proportions and compact eyelet are already proven.

## Make the tap obvious

Use the supplied 25 mm TAP TO PLAY artwork as a non-metal overlay on the programmed rear NFC tag. A 20-up print sheet and handoff card are included in `guides`. Trailer Swift also says TAP THE BASE on the stage top.

## Batch gate

Physically test one of each model, every NFC tag, and the thickest intended split ring before producing a batch.

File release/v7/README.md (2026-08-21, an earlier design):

# Rad Dad Retro Riot v7: Micro Replica Edition

**Old media. Loud band. One tap.**

This release contains pocket-size media relics: a compact cassette, a
3.5-inch floppy disk, a VHS cassette, and the Trailer Swift desk figure. Every
piece is designed around a visible 25 mm NFC interaction.

## Start with one test print

Print one individual model before using a combined plate. Confirm visual
identity, key-ring fit where applicable, NFC scanning, sticker protection, and
drop durability before batch production.

## 3MF status

Core 3MF files are **model-only geometry packages**. They do not contain a
printer, nozzle, filament, process, support, or plate profile. A file is a true
Bambu project only when it is explicitly named as a project and listed below as
created by the separate Bambu postprocessor.

- **Rad Dad Compact Cassette v37:** true Bambu project: `Rad_Dad_Cassette_v37_A1_MINI_0.4_PROJECT.3mf`.
- **Rad Dad 3.5-Inch Floppy v19:** true Bambu project: `Rad_Dad_Floppy_v19_A1_MINI_0.4_PROJECT.3mf`.
- **Rad Dad Mini VHS v4:** true Bambu project: `Rad_Dad_Mini_VHS_v4_A1_MINI_0.4_PROJECT.3mf`.
- **Rad Dad Micro Replicas v7 All-Four Plate:** true Bambu project: `Rad_Dad_Retro_Riot_v7_ALL_FOUR_A1_MINI_0.4_PROJECT.3mf`.
- **Trailer Swift v5 Punk Desk Toy:** true Bambu project: `Trailer_Swift_v5_Bobblehead_NFC_A1_MINI_0.4_PROJECT.3mf`.

Never infer print settings from a filename. Open each file in Bambu Studio,
select the A1 Mini and 0.4 mm nozzle profile, and review the sliced preview.

## NFC interaction

Program each non-metal 25 mm tag with `https://raddadband.com/tap/`. Apply the programmed 25 mm
tag ONTO the marked landing. Apply the matching media overlay on top, then use
the handoff card: **Find the marked circle. Touch your unlocked phone to it.**

PRINT NFC OVERLAYS ONLY ON NON-METALLIC PAPER OR VINYL. NEVER USE FOIL, METALLIC INK, OR METAL-BACKED LABEL STOCK.

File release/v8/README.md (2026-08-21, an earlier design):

# Rad Dad Retro Riot v8: QR Edition

**OLD MEDIA. LOUD BAND. ONE SCAN.**

This is the complete QR-first release of the Rad Dad cassette, floppy disk,
mini VHS, and Trailer Swift desk collectible. The proven v7 geometry is reused
byte-for-byte. A single visible 1-inch QR sticker now replaces the NFC tag,
programming step, and separate NFC overlay.

## Start here

| Need | File |
|---|---|
| Print on Avery 6450 or OnlineLabels OL1025 | [63-up PDF](guides/qr_stickers/Rad_Dad_QR_STICKERS_AVERY_6450_OL1025_63UP_US_LETTER.pdf) |
| Print on full-sheet sticker paper and hand cut | [35-up PDF](guides/qr_stickers/Rad_Dad_QR_STICKERS_HAND_CUT_35UP_US_LETTER.pdf) |
| Send artwork to a sticker vendor | [Individual SVG](guides/qr_stickers/Rad_Dad_1IN_QR_STICKER_VENDOR_MASTER.svg) |
| Check printer scaling first | [Calibration PDF](guides/qr_stickers/Rad_Dad_QR_STICKER_PRINT_CALIBRATION.pdf) |
| Install the labels | [QR setup guide](guides/QR_STICKER_SETUP.md) |
| Buy suitable stock | [Sticker sourcing guide](guides/STICKER_SOURCING.md) |
| Find each placement area | [Placement guide](guides/Rad_Dad_QR_STICKER_PLACEMENT_GUIDE.svg) |
| Print the models | Open the `3mf/` directory or use the universal files in `stl/` |

## QR specification

- Destination: `https://raddadband.com/tap/`
- Finished label: 25.4 mm / 1 inch round
- QR matrix: 29 x 29 modules, error correction Q
- Quiet zone: 4 modules on every side
- Printed QR square: 16.5 mm
- Module pitch: 0.446 mm
- Minimum model landing: 26.0 mm
- Artwork: black QR on white, 600 DPI and vector masters included

## Model geometry

V8 does not resize or remodel the collectibles. The copied STL and 3MF hashes
are recorded in `qa/MODEL_REUSE_PROVENANCE.json`; the v7 digital geometry
evidence is retained under `qa/v7_geometry_evidence/`.

## Distribution gate

Do not hand out a piece until its installed QR code opens the Rad Dad tap page
from the normal camera on both iPhone and Android. Repeat the scan after the
adhesive has cured for 24 hours.

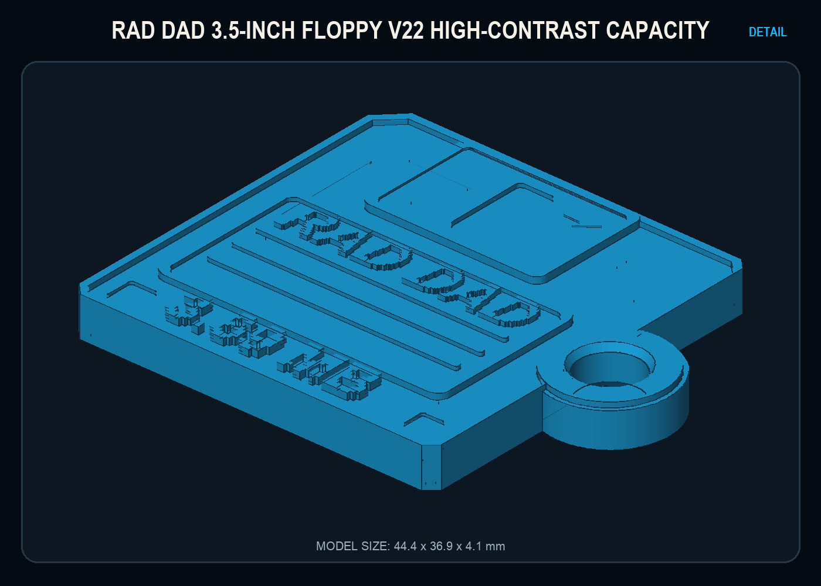
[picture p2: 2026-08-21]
release/v9/previews/Rad_Dad_Floppy_v22_DETAIL.png

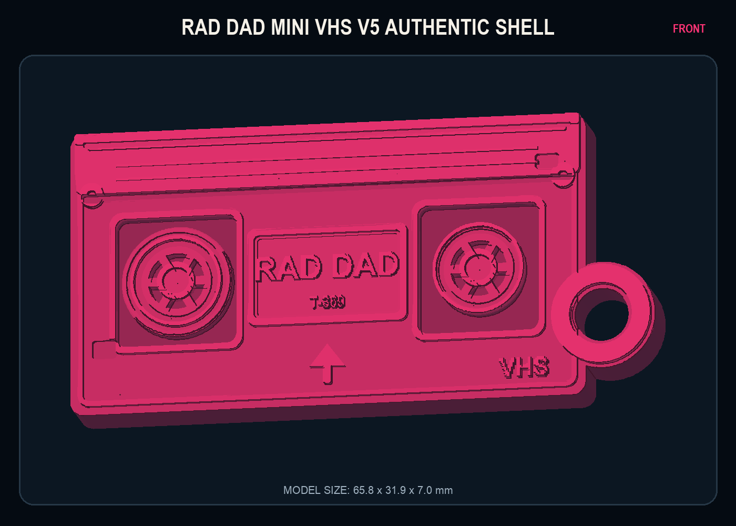
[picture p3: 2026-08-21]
release/v9/previews/Rad_Dad_Mini_VHS_v5_FRONT.png

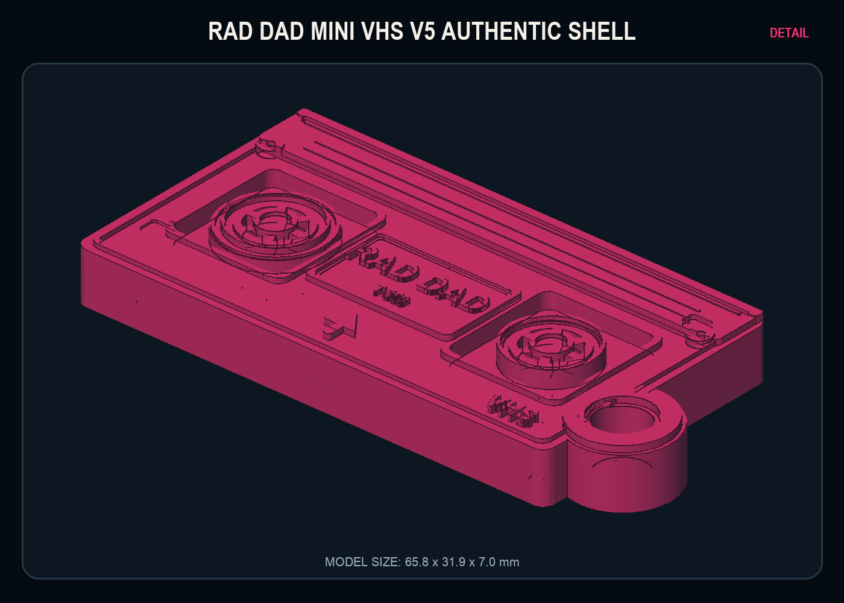
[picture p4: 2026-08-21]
release/v9/previews/Rad_Dad_Mini_VHS_v5_DETAIL.png

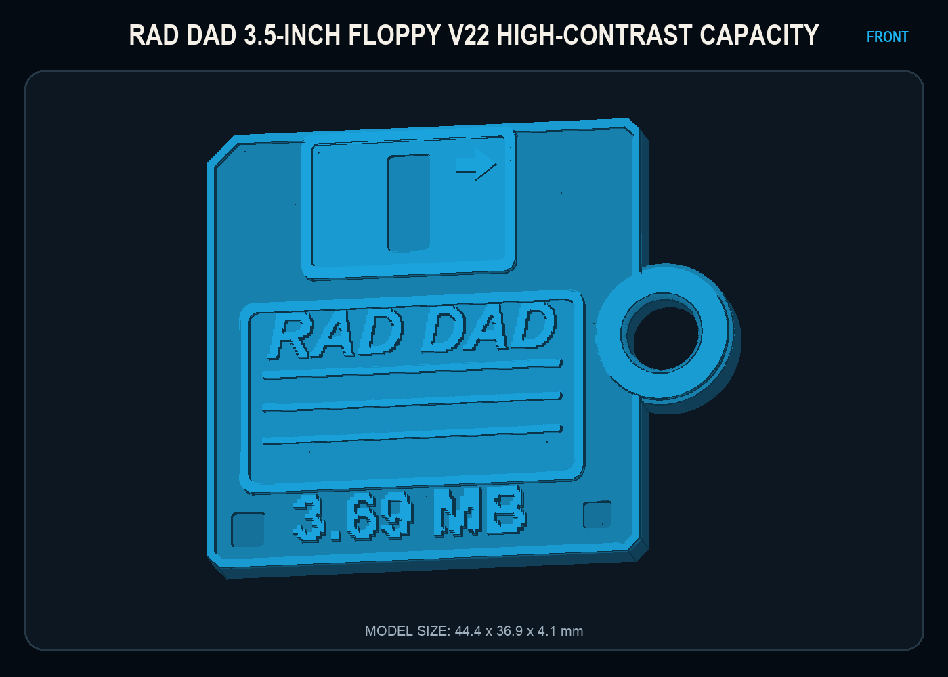
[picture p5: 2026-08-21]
release/v9/previews/Rad_Dad_Floppy_v22_FRONT.png

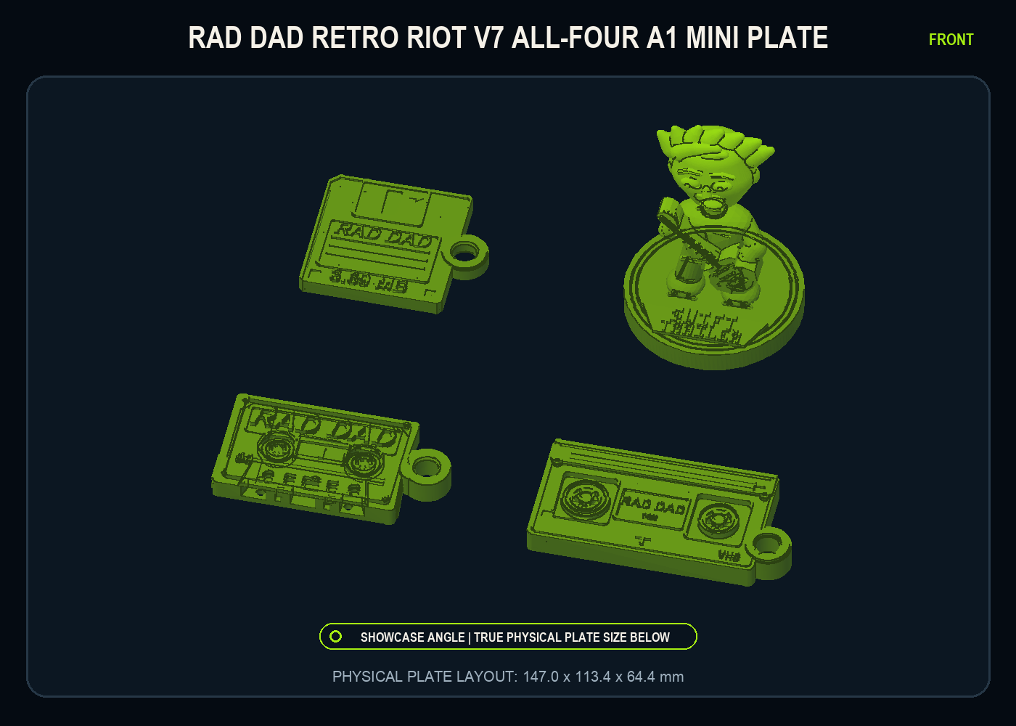
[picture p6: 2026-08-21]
release/v9/previews/Rad_Dad_Retro_Riot_v9_ALL_FOUR_FRONT.png

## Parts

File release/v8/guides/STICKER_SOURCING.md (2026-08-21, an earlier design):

# Where to get the 1-inch QR stickers

## Best balance of speed, cost, and durability

**OnlineLabels OL1025WJ weatherproof matte inkjet** is the recommended small-batch
production stock. It is a true 1-inch circle, 63 labels per US Letter sheet,
has a weatherproof matte face, accepts the supplied 63-up file, has no minimum,
and the vendor advertises same-business-day shipping for in-stock orders placed
before 5 p.m. ET.

https://www.onlinelabels.com/products/ol1025wj

## Cheapest immediate proof stock

**Avery 6450** is a widely available 1-inch round sheet with the exact same
63-up layout. It works in laser and inkjet printers and is inexpensive per
label, but it is removable matte paper. Use it for fit and scan proofs, not for
final keychain batches exposed to abrasion or moisture.

https://www.avery.com/products/labels/6450

## Professional finished batch

**Sticker it custom 1-inch round stickers** are laminated, water resistant,
scratch resistant, supplied with a free proof, and advertised to ship in a few
days. Upload the individual SVG or 600 DPI PNG vendor master. Choose white
vinyl, matte or gloss laminate, exact 1-inch circle, and no metallic material.

https://www.stickerit.co/en-us/custom-stickers/custom-1-inch-round-stickers

## Same-day emergency option

Staples offers same-day pickup on select custom labels ordered before noon.
Confirm that the selected store can produce an exact 1-inch circle at 100%
scale before ordering. Upload the vendor PDF and request one physical proof.

https://www.staples.com/services/printing/custom-labels-stickers/

## Purchase rule

Order a small proof quantity first. Do not approve a production batch until
three labels from the top, center, and bottom of the sheet scan correctly and
measure 25.4 mm.

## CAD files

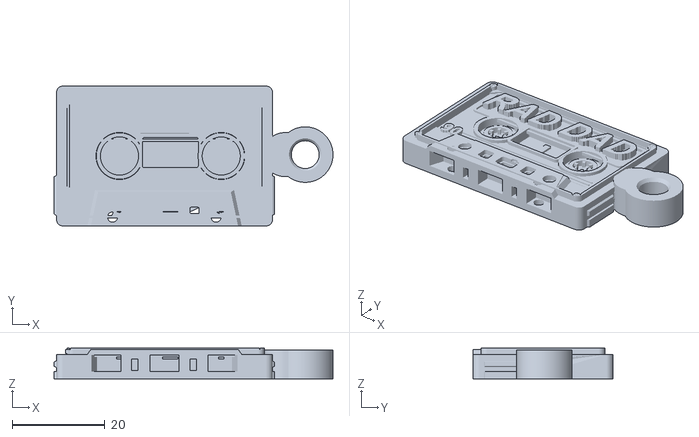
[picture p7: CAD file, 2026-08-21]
assets/cad/Rad_Dad_Cassette_v36_COMPACT_WIDE_WIRE_EYELET_BODY.stl
60.3 x 30.3 x 6.69

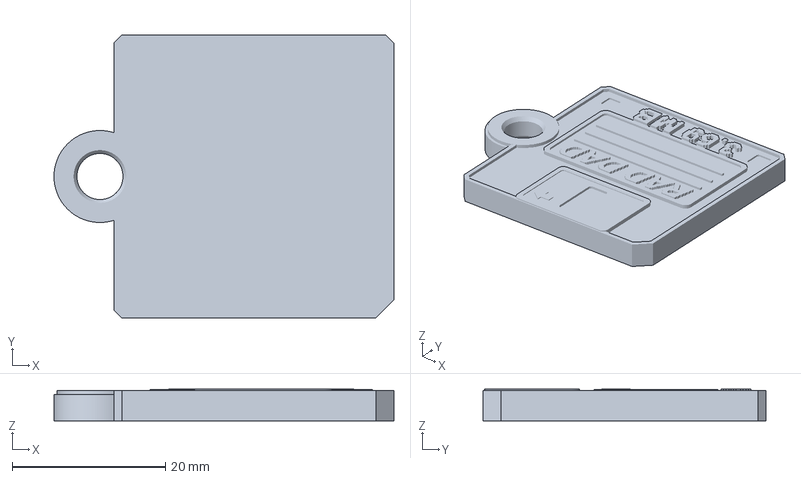
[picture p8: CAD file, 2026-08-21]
release/v9/3mf/Rad_Dad_Floppy_v22_A1_MINI_0.4_PROJECT.3mf
44.4 x 36.9 x 4.13 mm

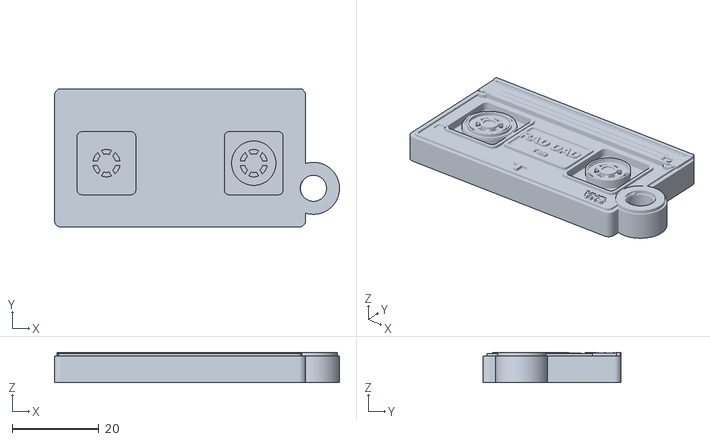
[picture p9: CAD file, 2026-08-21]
release/v9/stl/Rad_Dad_Mini_VHS_v5_BINARY.stl
65.8 x 31.9 x 7.00

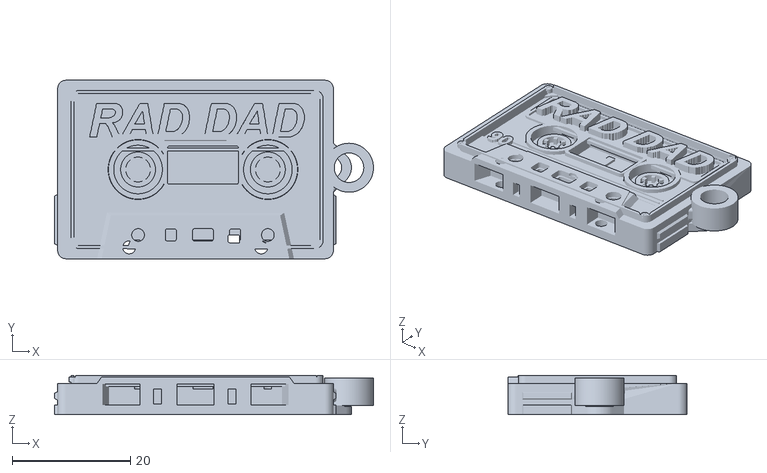
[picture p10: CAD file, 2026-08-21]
assets/cad/Rad_Dad_Cassette_v33_FINAL_AUDITED_BODY.stl
54.1 x 30.3 x 6.69

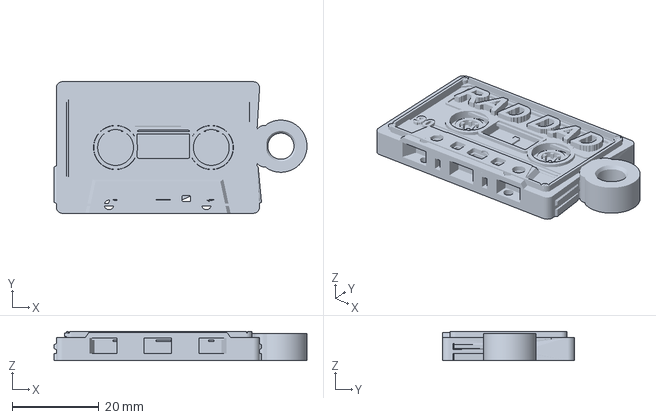
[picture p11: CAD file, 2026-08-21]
release/v9/3mf/Rad_Dad_Cassette_v38_A1_MINI_0.4_PROJECT.3mf
58.2 x 30.3 x 6.69 mm

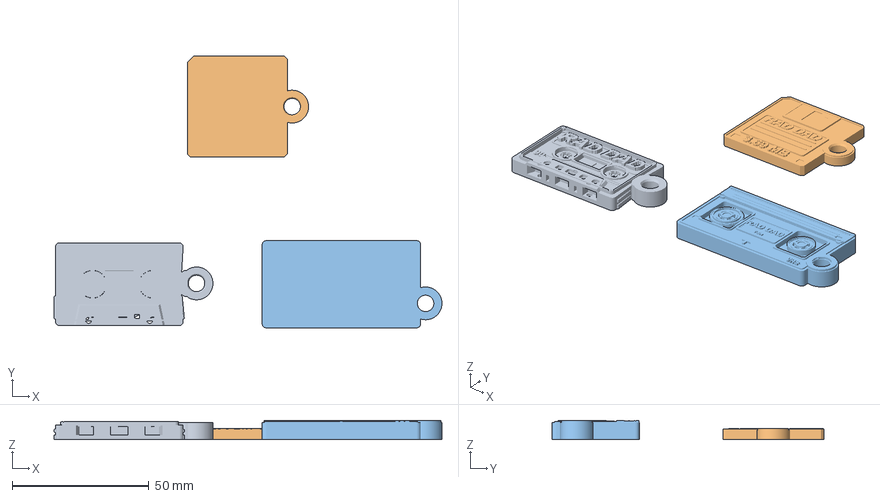
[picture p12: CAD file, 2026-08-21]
release/v9/3mf/Rad_Dad_Retro_Riot_v9_CURRENT_THREE_CASSETTE_FLOPPY_VHS_A1_MINI_0.4_PROJECT.3mf
142.0 x 99.4 x 7.00 mm
Rad Dad Compact Cassette v38 Authentic Edge
Rad Dad 3.5-Inch Floppy v22 High-Contrast Capacity
Rad Dad Mini VHS v5 Authentic Shell

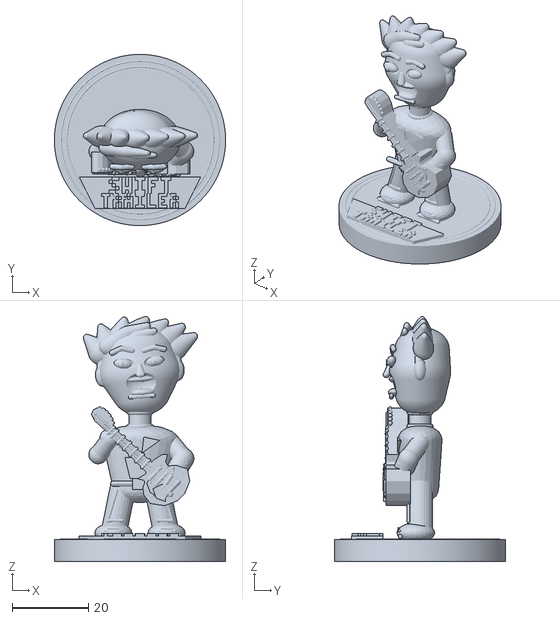
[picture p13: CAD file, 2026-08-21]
release/v9/stl/Trailer_Swift_v16_Strat_Style_Punk_QR_BINARY.stl
45.0 x 45.0 x 64.4

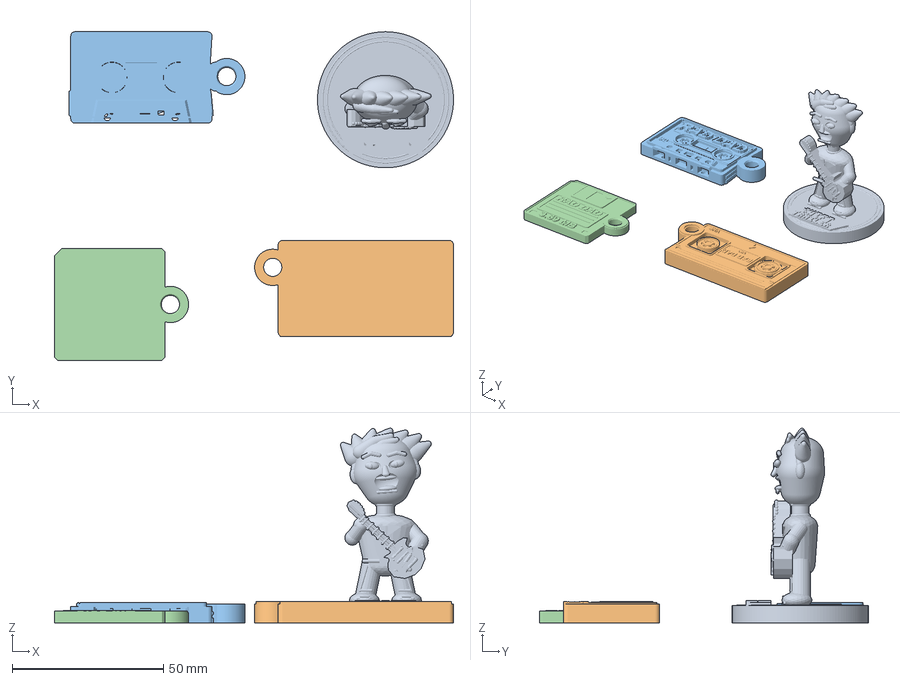
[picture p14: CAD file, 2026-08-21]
release/v9/3mf/Rad_Dad_Retro_Riot_v9_ALL_FOUR_A1_MINI_0.4_PROJECT.3mf
132.0 x 108.7 x 64.4 mm
Trailer_Swift_v16_Strat_Style_Punk_QR_BINARY.stl
Rad_Dad_Mini_VHS_v5_BINARY.stl
Rad_Dad_Cassette_v38_BINARY.stl
Rad_Dad_Floppy_v22_BINARY.stl

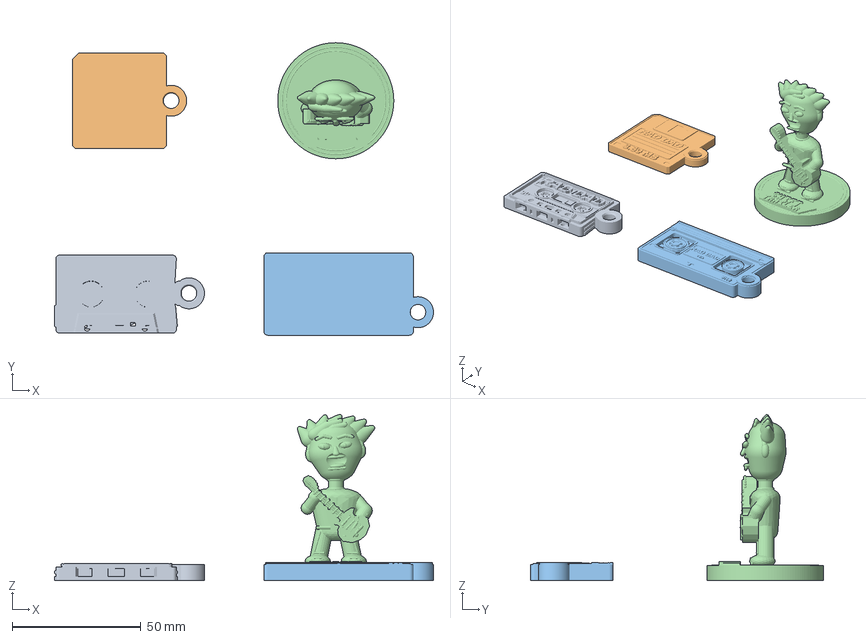
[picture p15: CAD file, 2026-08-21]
release/v9/3mf/Rad_Dad_Retro_Riot_v9_ALL_FOUR_A1_MINI_0.4_TREE_SUPPORT_PROJECT.3mf
147.0 x 113.4 x 64.4 mm
Rad Dad Compact Cassette v38 Authentic Edge
Rad Dad 3.5-Inch Floppy v22 High-Contrast Capacity
Rad Dad Mini VHS v5 Authentic Shell
Trailer Swift v16 Strat-Style Punk Collectible

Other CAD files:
release/v9/stl/Rad_Dad_Cassette_v38_BINARY.stl
release/v9/3mf/Trailer_Swift_v16_Strat_Style_Punk_QR_A1_MINI_0.4_PROJECT.3mf
release/v9/stl/Rad_Dad_Floppy_v22_BINARY.stl
release/v9/3mf/Rad_Dad_Mini_VHS_v5_A1_MINI_0.4_PROJECT.3mf
release/v9/3mf/Rad_Dad_Mini_VHS_v5_MODEL_ONLY.3mf
release/v9/3mf/Rad_Dad_Floppy_v22_MODEL_ONLY.3mf
release/v9/3mf/Trailer_Swift_v16_Strat_Style_Punk_QR_MODEL_ONLY.3mf
release/v9/3mf/Rad_Dad_Cassette_v38_MODEL_ONLY.3mf
release/v9/3mf/Rad_Dad_Retro_Riot_v9_ALL_FOUR_MODEL_ONLY.3mf
release/v6/3mf/Rad_Dad_Cassette_v36_SINGLE_TEST_A1_MINI.3mf
release/v6/3mf/Rad_Dad_Floppy_v18_SINGLE_TEST_A1_MINI.3mf
release/v6/3mf/Rad_Dad_Mini_VHS_v3_SINGLE_TEST_A1_MINI.3mf
release/v6/3mf/Rad_Dad_Retro_Riot_v6_ALL_FOUR_A1_MINI.3mf
release/v6/3mf/Trailer_Swift_v4_Bobblehead_NFC_SINGLE_TEST_A1_MINI.3mf
release/v6/stl/Rad_Dad_Floppy_v18.stl
release/v6/stl/Rad_Dad_Mini_VHS_v3.stl
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

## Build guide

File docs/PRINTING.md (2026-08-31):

# Rad Dad Retro Riot v9 production guide

## Start with the configured projects

Use files under `release/v9/3mf/`. Model-only 3MF and STL files contain valid
geometry but do not carry the complete Bambu printer intent.

| Need | Recommended file |
|---|---|
| Cassette only | `Rad_Dad_Cassette_v38_A1_MINI_0.4_PROJECT.3mf` |
| Floppy only | `Rad_Dad_Floppy_v22_A1_MINI_0.4_PROJECT.3mf` |
| VHS only | `Rad_Dad_Mini_VHS_v5_A1_MINI_0.4_PROJECT.3mf` |
| Trailer Swift only | `Trailer_Swift_v16_Strat_Style_Punk_QR_A1_MINI_0.4_PROJECT.3mf` |
| Current cassette, floppy, and VHS together | `Rad_Dad_Retro_Riot_v9_CURRENT_THREE_CASSETTE_FLOPPY_VHS_A1_MINI_0.4_PROJECT.3mf` |
| All four with Trailer Swift support | `Rad_Dad_Retro_Riot_v9_ALL_FOUR_A1_MINI_0.4_TREE_SUPPORT_PROJECT.3mf` |

All files are unsliced projects. Opening successfully does not replace Preview
inspection or a physical proof print.

## Approved baseline

- Printer: Bambu Lab A1 mini.
- Nozzle: 0.4 mm.
- Material: dry PLA for the qualification print.
- Plate: clean Textured PEI Plate.
- Scale: exactly 100% on all axes.
- Layer height: 0.16 mm.
- Initial layer height: 0.20 mm.
- Wall loops: 4.
- Top layers: 5.
- Bottom layers: 5.
- Infill: 30% gyroid.
- Small perimeters: 25 mm/s.
- Top surfaces: 30 mm/s.
- Elephant-foot compensation: 0.15 mm.

Cassette, floppy, and VHS print flat with supports off. Trailer Swift prints
upright with tree/organic support from the build plate. The current three-device
plate has supports off. Use the all-four support project only when printing the
figure with the media pieces.

## Before every print

1. Confirm the project filename and model revisions.
2. Confirm the A1 Mini, 0.4 mm nozzle, Textured PEI Plate, and 100% scale.
3. Confirm every object is fully inside the 180 x 180 mm build area.
4. Slice at 0.16 mm using Arachne wall generation.
5. Review every layer in Preview, not only the final top view.
6. Confirm the eyelet bores are open and contain no support or brim.
7. Confirm no front lettering becomes an isolated or floating toolpath.
8. Print one proof before starting a batch.

## Device-specific Preview checks

### Cassette v38

- Confirm the complete lower transport edge is present.
- Confirm all five lower-edge transport bays are open at the physical edge.
- Confirm unequal tape packs, six-lobe hubs, center window, and pressure pad.
- Confirm `RAD DAD`, `90`, and `C-69` remain readable.
- Confirm the rear landing stays continuous and supports are off.

### Floppy v22

- Confirm the shutter is above the writable label.
- Confirm `RAD DAD` remains inside the label field.
- Confirm every character of the 20.00 x 4.00 mm bold `3.69 MB` mark has a
  continuous toolpath.
- Confirm the rear spindle, tracks, seam, and write-protect cues remain distinct.
- Confirm the 6.0 mm eyelet is open and supports are off.

### Mini VHS v5

- Confirm two independent reel windows and asymmetric tape packs.
- Confirm the dust cover, tape path, hubs, label, `VHS`, and `T-369` details.
- Confirm `RAD DAD` is large and readable on the label.
- Reject a Preview that reads like a stretched audio cassette.
- Confirm the rear landing is flat and supports are off.

### Trailer Swift v16

- Confirm the figure and base remain one object.
- Confirm feet, guitar, hands, neck, hair, and nameplate are supported.
- Confirm supports begin on the build plate and remain removable.
- Confirm the underside sticker landing is not filled by support or raft.

## Current three-device plate

The current plate contains only the cassette, v22 floppy, and VHS. They are
spaced across the A1 Mini bed with the floppy centered above the longer pair:

- Cassette bounds: X 19.02-77.18 mm, Y 39.87-70.13 mm.
- Floppy bounds: X 67.82-112.18 mm, Y 101.54-138.46 mm.
- VHS bounds: X 95.20-161.00 mm, Y 39.05-70.95 mm.

Print by layer. Do not enable support. Stop before printing if a local profile
substitution changes the plate, scale, orientation, or support state.

## Physical inspection after cooling

- Measure the model envelope and 6.0 mm keyring opening.
- Confirm every model sits flat without rocking.
- Confirm all text is complete and joined to the shell.
- Read `RAD DAD` at arm's length and `3.69 MB` at 30 cm / 12 inches in ordinary
  indoor light.
- Inspect the cassette transport edge from the front and physical bottom.
- Inspect the floppy front and back as separate, developed faces.
- Inspect the VHS from the front, side, and back for VHS-specific hardware.
- Reject cracks, strings, open seams, loose details, sharp cleanup scars,
  delamination, or exposed infill.

## Keyring qualification

Applies to cassette, floppy, and VHS:

1. Measure the thickest intended production split-ring wire.
2. Install it through the eyelet by hand in 30 seconds or less.
3. Use no drill, knife, forced prying, or heat.
4. Reject whitening, cracking, gouging, peeling, or visible bore shaving.
5. Apply a 2 kg static hanging load for 60 seconds.
6. Complete 25 firm pull-and-twist cycles.
7. Reinspect the bore and both eyelet roots.

## QR sticker installation

1. Use a 25.4 mm matte-white permanent-adhesive sticker. Preferred artwork is
   a pure-black QR. If black ink is unavailable, use the official
   `Rad_Dad_QR_RED_` fallback, print it as color rather than grayscale, and
   scan-test the red calibration page first. Avery 6450 is removable-adhesive
   proof-only stock. It does not meet this permanent-adhesive requirement.
   Every finished or carried piece requires permanent adhesive; reject
   removable stock.
2. Confirm it opens `https://raddadband.com/qr/` before installation.
3. Clean and dry the protected rear or underside landing.
4. Center the sticker without covering an edge, opening, or raised detail.
5. Press the full sticker for 20-30 seconds.
6. Allow the adhesive to cure according to the stock manufacturer's guidance.
7. Scan the installed code three times on iPhone and three times on Android.
8. Repeat scans after drop and carry testing.

Previously ordered stickers encoding `https://raddadband.com/tap/` remain valid
through the website's permanent redirect. Do not discard them.

## Troubleshooting

| Symptom | Required response |
|---|---|
| `3.69 MB` is incomplete | Confirm v22, 100% scale, 0.4 mm nozzle, 0.16 mm Arachne profile, and slow detail speeds; hold the batch if any character remains incomplete |
| Eyelet is tight | Confirm elephant-foot compensation, remove loose brim only, and reject cracked or undersized parts |
| Cassette bottom looks solid | Confirm the v38 project and rear-down orientation; do not substitute an earlier simplified cassette |
| VHS resembles an audio cassette | Confirm v5 and inspect the independent reel windows, door, label, and VHS marks |
| QR does not scan | Check lighting, focus distance, quiet zone, print scaling, glare, sticker damage, and destination URL; replace the sticker if needed |
| Sticker edge lifts | Clean the landing, replace the sticker, press the full surface, and allow complete cure time |
| Trailer Swift support damages details | Remove support gradually; reorient or adjust tree support before another print |

## Automated release verification

Run from the repository root after rebuilding:

```bash
python3 tools/verify_v9_release.py
```

Automated success proves file integrity, package consistency, QR specification,
and digital mesh QA. It does not replace the physical proof and acceptance
steps in [VALIDATION.md](VALIDATION.md).

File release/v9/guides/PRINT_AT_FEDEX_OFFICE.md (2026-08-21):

# Print the QR stickers at FedEx Office

## File to bring

Use `guides/qr_stickers/Rad_Dad_QR_FEDEX_OFFICE_FULL_SHEET_48UP_US_LETTER.pdf` for the standard black full sheet. If black ink is
unavailable, use `guides/qr_stickers/Rad_Dad_QR_RED_FEDEX_OFFICE_FULL_SHEET_48UP_US_LETTER.pdf` and first print
`guides/qr_stickers/Rad_Dad_QR_RED_PRINT_CALIBRATION_US_LETTER.pdf`. Both layouts cut or punch into one-inch circles.
Bring `guides/qr_stickers/Rad_Dad_QR_PRINT_CALIBRATION_US_LETTER.pdf` as the standard black proof page.

## Counter instructions

1. Print on US Letter, white matte adhesive label stock.
2. Print black on white, or use the supplied pure-red fallback on white. Do not
   use grayscale, clear, metallic, holographic, or dark stock.
3. Select Actual Size / 100%. Disable Fit, Shrink, Scale to Fit, borderless
   enlargement, and automatic rotation.
4. Keep the PDF at its native resolution. Do not screenshot or resave it.
5. Print one calibration proof before the sticker sheet.
6. Confirm the calibration circle is exactly 25.4 mm and its reference square
   is exactly 50.0 mm.
7. Scan the proof with an iPhone and Android phone before approving the sheet.
8. Ask whether the store can circle-cut at exactly one inch. If not, use a
   one-inch craft punch or cut just outside the supplied circular guide.

Matte stock is preferred because it reduces glare. If only glossy adhesive
stock is available, approve it only after scanning under bright overhead light.

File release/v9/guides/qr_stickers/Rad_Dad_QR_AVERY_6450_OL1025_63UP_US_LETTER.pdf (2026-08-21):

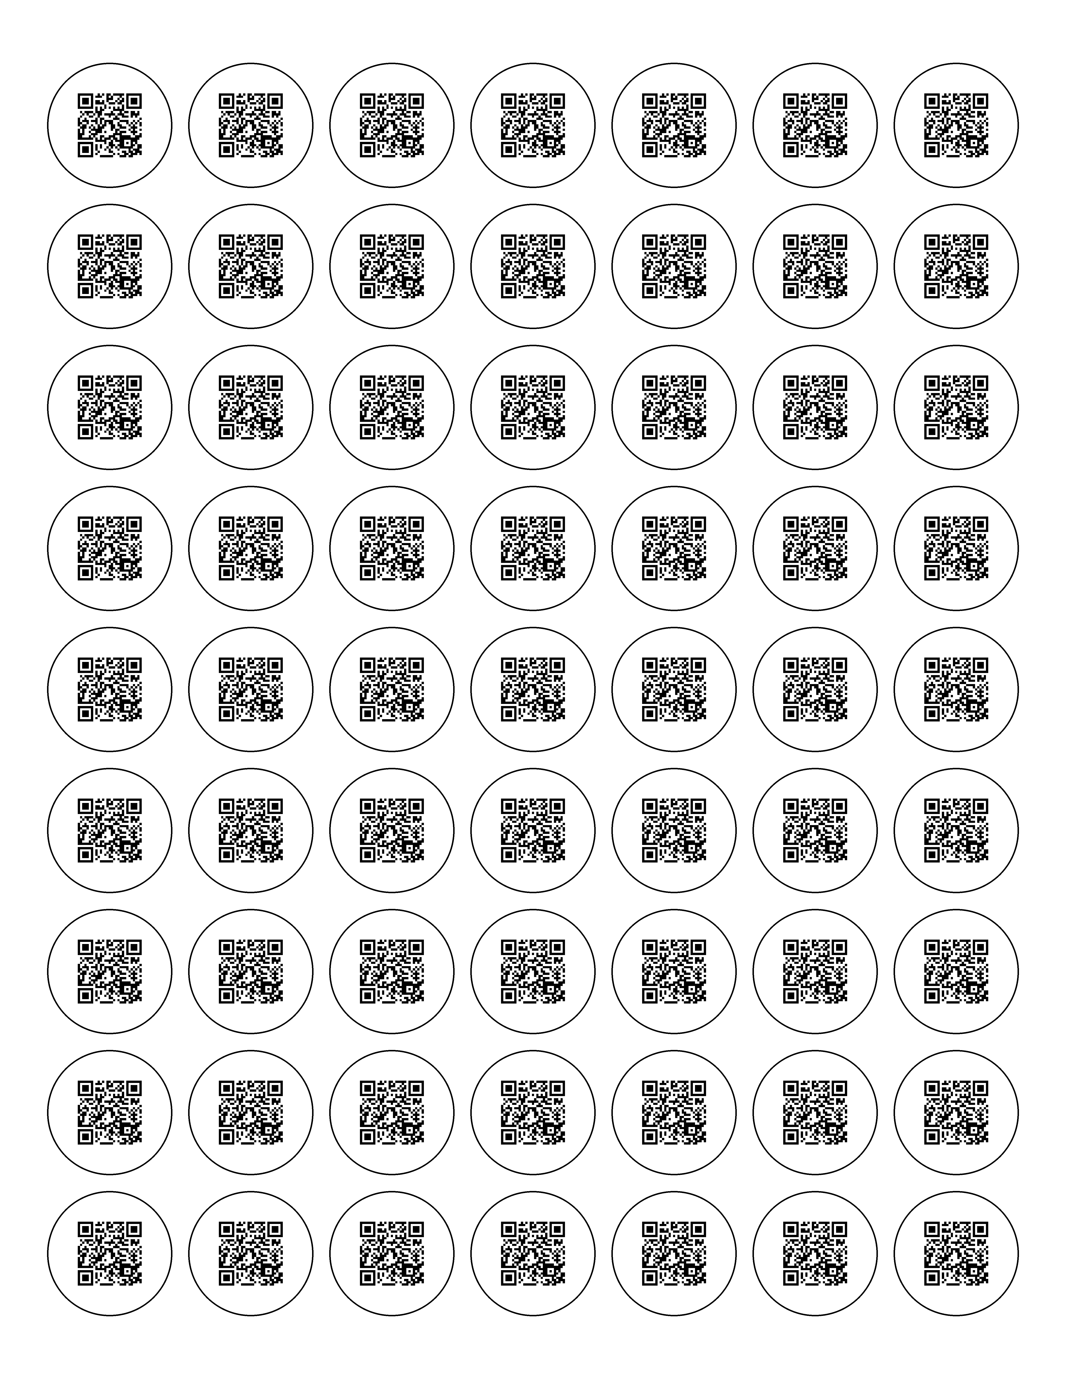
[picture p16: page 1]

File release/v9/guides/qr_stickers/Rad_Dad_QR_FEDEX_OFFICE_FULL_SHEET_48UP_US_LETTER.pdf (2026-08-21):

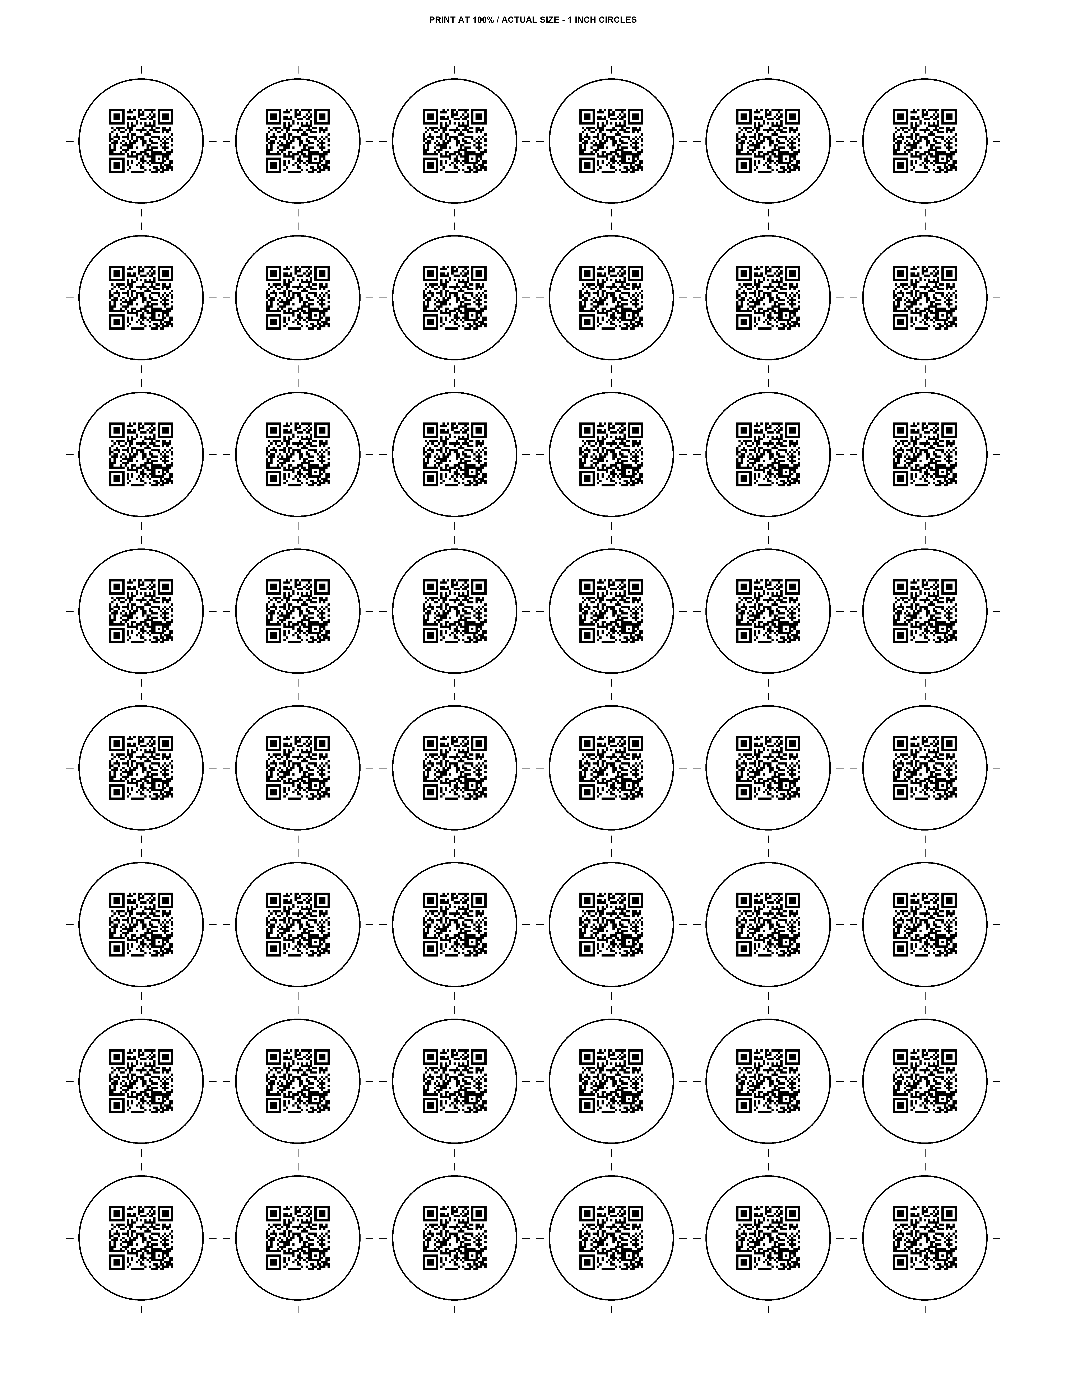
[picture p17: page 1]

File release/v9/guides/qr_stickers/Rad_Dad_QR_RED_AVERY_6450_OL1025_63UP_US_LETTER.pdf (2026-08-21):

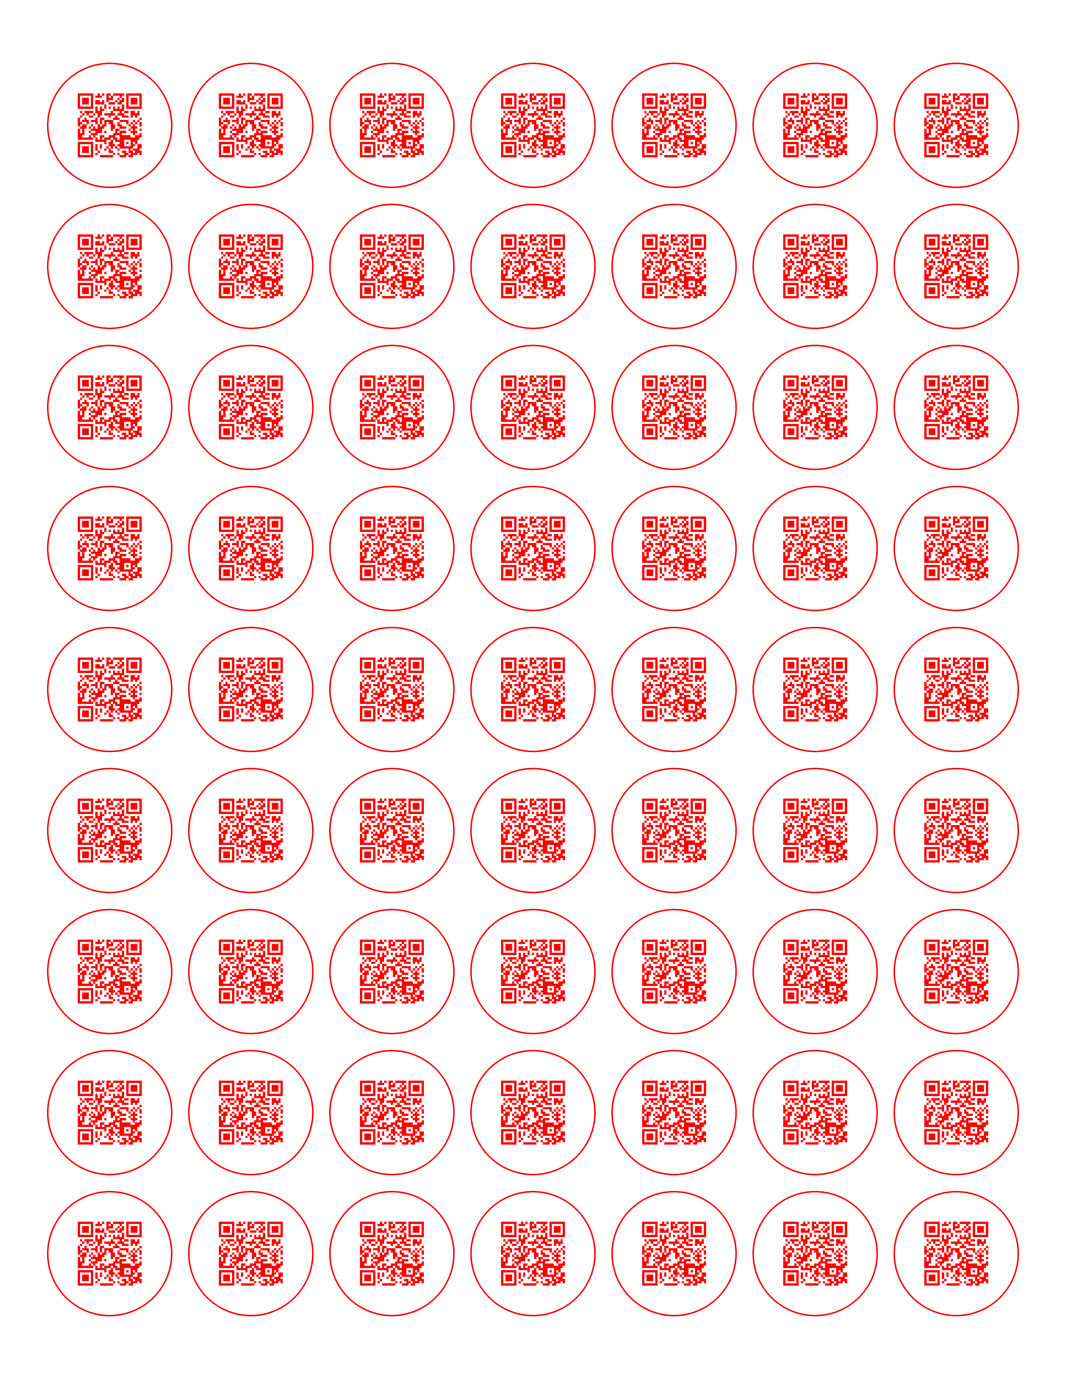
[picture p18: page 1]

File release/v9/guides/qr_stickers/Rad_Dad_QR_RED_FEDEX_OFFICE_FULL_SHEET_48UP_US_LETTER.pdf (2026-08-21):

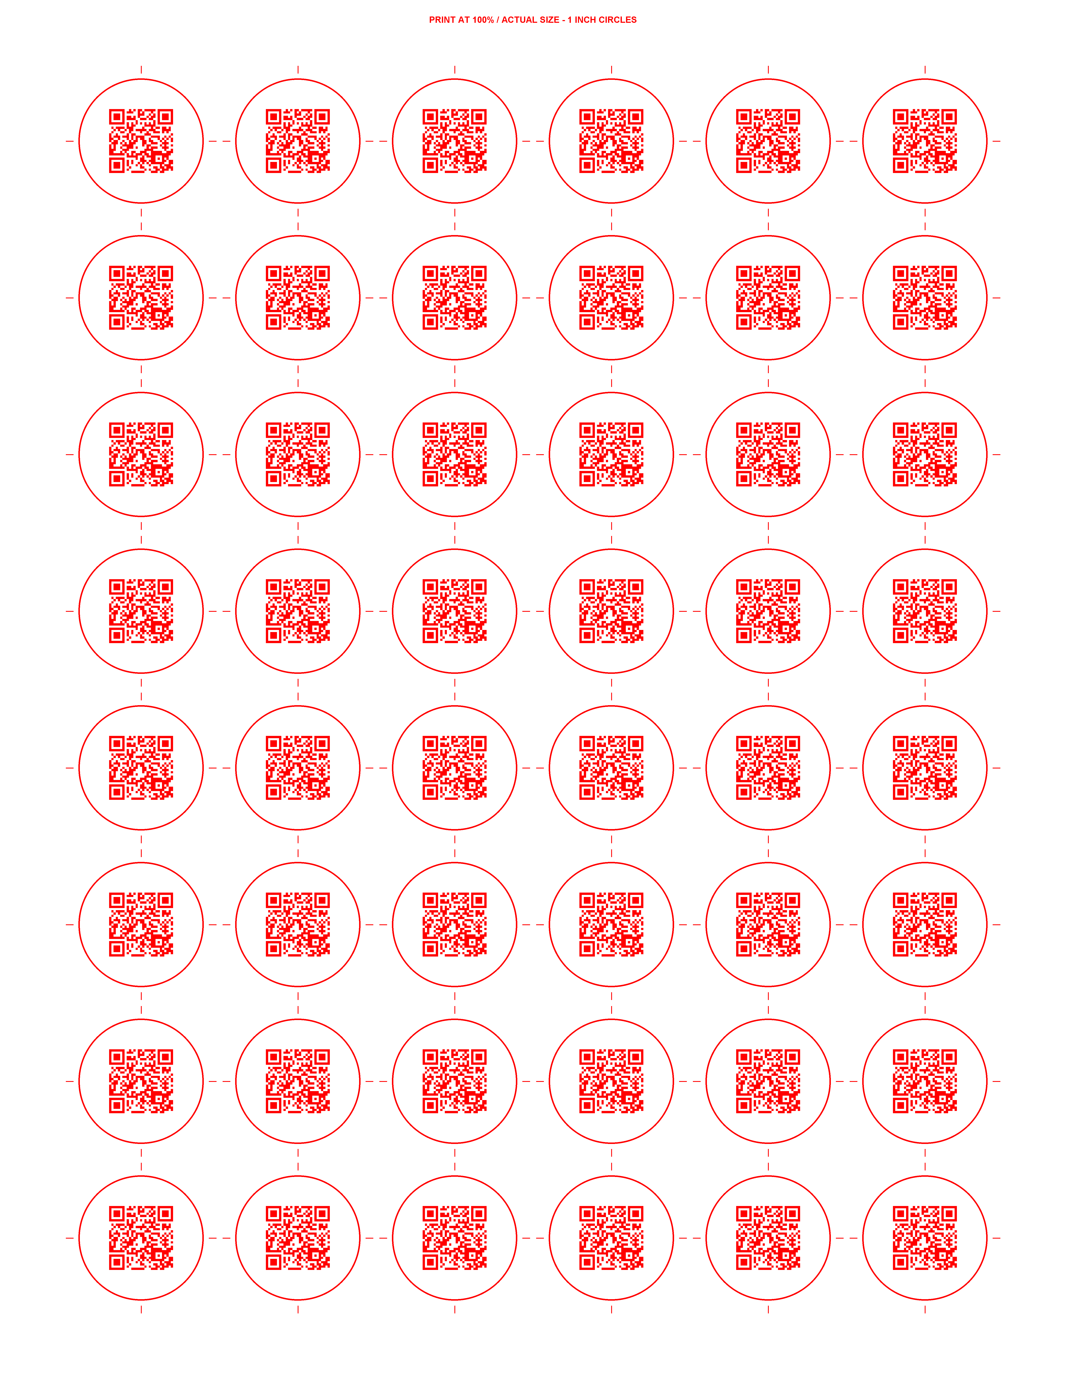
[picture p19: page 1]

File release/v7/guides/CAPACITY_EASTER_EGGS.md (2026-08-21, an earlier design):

# Capacity easter eggs

The three media replicas share one quiet `369` joke while staying faithful to
the labeling language of the original format.

| Replica | Mark | Why it belongs |
|---|---|---|
| Compact cassette | `C-69` | Styled like a cassette duration designation. |
| 3.5-inch floppy | `3.69 MB` | Styled like a disk capacity marking. |
| VHS | `T-369` | Styled like a VHS running-time or tape-grade mark. |
| Trailer Swift | None | The character and nameplate remain the entire joke. |

The marks are intentionally secondary. `RAD DAD` and the hardware silhouette
must remain readable first. Matching 25 mm NFC overlays repeat each media cue
without using foil, metallic ink, or metal-backed label stock.

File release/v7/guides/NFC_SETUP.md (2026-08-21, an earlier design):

# NFC setup and overlay production

1. Use a genuine, non-metal, peel-and-stick 25 mm NFC tag.
2. Encode the HTTPS address `https://raddadband.com/tap/`.
3. Test the loose tag on iPhone and Android before locking it.
4. Apply the programmed 25 mm tag ONTO the marked landing.
5. Apply the matching non-metal overlay on top of the programmed tag.
6. Scan again after the printed overlay is installed.
7. Apply a clear, non-metal self-adhesive vinyl or PET overlaminate over the
   printed overlay. Burnish from the center outward without trapping bubbles.
   Do not use foil, holographic, metallized, metal-backed, or metallic-ink film.
8. **Mandatory final gate:** scan the completed piece again on iPhone and
   Android after the overlaminate is installed. Do not distribute a piece that
   fails this final scan.
9. Scan once more after the adhesive has cured for 24 hours.

## Artwork production

- Individual 25 mm PNG, SVG, and PDF overlay files are finished trim-size
  assets for precut 25 mm stock or vendor workflows that request trim artwork.
- The 20-up PDF sheets are the hand-cut and print-and-cut masters. They retain
  a true 25 mm finished cut circle plus 1 mm bleed around every label.
- PDF files are the vendor-print masters. Send the PDF rather than a screenshot
  or resaved raster image, print at 100%, and prohibit automatic scaling.
- Cut on the 25 mm hairline. The surrounding 1 mm bleed is sacrificial and is
  not part of the finished label.

## Handoff card commercial printing

- Finished trim size: 3.5 x 2 inches (88.9 x 50.8 mm).
- Supplied artwork includes 0.125 inch (3.175 mm) bleed on all four sides,
  external crop marks, and an embedded PDF TrimBox at the finished size.
- Print duplex at 100% and **flip on the short edge**. Confirm front/back
  orientation on one proof before ordering or producing the full quantity.
- Keep crop marks and bleed in the submitted master; the printer trims them
  away. Do not fit or scale the artwork to the sheet.

## Placement

- Cassette: marked circle on the flat rear landing; use the `C-69 // SIDE A` overlay.
- Floppy: marked rear circle; the 25 mm overlay contains an approximately
  11-12 mm faux gray hub.
- VHS: marked flat rear landing; use the `T-369` video-label overlay.
- Trailer Swift: underside of the circular base; use `TAP THE BASE`.

The printed overlay does not replace the NFC tag. PRINT NFC OVERLAYS ONLY ON NON-METALLIC PAPER OR VINYL. NEVER USE FOIL, METALLIC INK, OR METAL-BACKED LABEL STOCK.
Printed gray on the floppy label is an ink illusion, not metal.

The handoff card includes a QR fallback to `https://raddadband.com/tap/` for phones that do not
read the NFC tag immediately.

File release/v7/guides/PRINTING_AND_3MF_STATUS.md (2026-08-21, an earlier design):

# Printing and 3MF package status

## Model-only Core 3MF

The Core writer in `src/v7_release_packaging.py` packages meshes, object names,
metadata, and an optional thumbnail. It does **not** embed Bambu printer or
process settings. Model-only files should include `MODEL_ONLY` in their names.

## True Bambu project 3MF

A true project file must be generated through a separate Bambu-specific
postprocessor implementing `BambuProjectPostprocessor`. The postprocessor must
embed an explicit A1 Mini / 0.4 mm nozzle profile and verify the resulting file.
Only those files should include `A1_MINI_0.4_PROJECT` in their names.

## Required v7 print intents

| Model | Printer/nozzle | Layer | Supports | Orientation |
|---|---|---:|---|---|
| Rad Dad Compact Cassette v37 | Bambu Lab A1 mini, 0.4 mm | 0.16 mm | off | flat |
| Rad Dad 3.5-Inch Floppy v19 | Bambu Lab A1 mini, 0.4 mm | 0.16 mm | off | flat |
| Rad Dad Mini VHS v4 | Bambu Lab A1 mini, 0.4 mm | 0.16 mm | off | flat |
| Rad Dad Micro Replicas v7 All-Four Plate | Bambu Lab A1 mini, 0.4 mm | 0.16 mm | organic, build plate only | mixed |
| Trailer Swift v5 Punk Desk Toy | Bambu Lab A1 mini, 0.4 mm | 0.16 mm | organic, build plate only | upright |

The individual cassette, floppy, and VHS projects use supports off. The
individual Trailer Swift project uses organic supports restricted to the build
plate. The all-four combined Bambu project uses global `tree(auto)` supports,
restricted to the build plate, so Trailer Swift can print on the same plate.
Before printing the combined project, open Preview and confirm that no
unnecessary support is generated beneath or around the cassette, floppy, or
VHS. If media support appears, correct the object-level support assignment and
slice again. These are explicit intents, not proof that a Core 3MF contains
those settings. Review every sliced layer, especially eyelets, blind recesses,
the VHS door, the figure neck, guitar, flames, feet, and underside NFC landing.

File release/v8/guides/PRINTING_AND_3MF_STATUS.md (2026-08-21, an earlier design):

# Printing and 3MF status

V8 changes the interaction layer only. Every STL and 3MF in this pack is an
exact byte-for-byte copy of the v7 Micro Replica Edition file. The cassette,
floppy, VHS, Trailer Swift figure, model dimensions, eyelets, support intents,
and Bambu profiles are unchanged.

Use the `_A1_MINI_0.4_PROJECT.3mf` files for embedded Bambu settings. Use the
`_MODEL_ONLY.3mf` or binary STL files when selecting your own slicer profile.
The all-four Bambu project remains the current combined plate.

Print one of each before batch production and review every sliced layer. The
QR sticker is installed only after the print has cooled, been inspected, and
the landing has been cleaned.

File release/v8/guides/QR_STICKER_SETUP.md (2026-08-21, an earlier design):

# QR sticker setup

## What changed

The NFC tag and NFC overlay have been replaced by one visible QR sticker. The
sticker itself tells the recipient what to do, opens with the standard camera,
and does not need NFC programming or a separate `TAP ME` layer.

## Encoded address

`https://raddadband.com/tap/`

The QR is static, but the address is controlled by Rad Dad. Keep this route live
and update the landing page behind it rather than changing the printed code.

## Install

1. Print the calibration page at **Actual Size / 100%**. Disable Fit, Shrink,
   Scale to Fit, and borderless enlargement.
2. Confirm the reference circle measures 25.4 mm and the 50 mm square measures
   50 mm.
3. Scan one ordinary-paper proof with an iPhone and Android phone.
4. Print the 63-up file on Avery 6450 or OnlineLabels OL1025 stock, or send the
   individual vendor master to a sticker printer.
5. Scan three labels from different areas of the sheet before peeling them.
6. Clean the model landing with 70% isopropyl alcohol and allow it to dry.
7. Center the sticker in the existing circular landing and press for 30 seconds.
8. Allow the adhesive to cure for 24 hours before keychain carry.
9. Scan every finished piece from the normal camera app before distribution.

## Acceptance rule

A finished piece passes only when the QR opens `https://raddadband.com/tap/` with the normal
camera on both iPhone and Android, with an ordinary phone case installed, in
indoor light and bright daylight.

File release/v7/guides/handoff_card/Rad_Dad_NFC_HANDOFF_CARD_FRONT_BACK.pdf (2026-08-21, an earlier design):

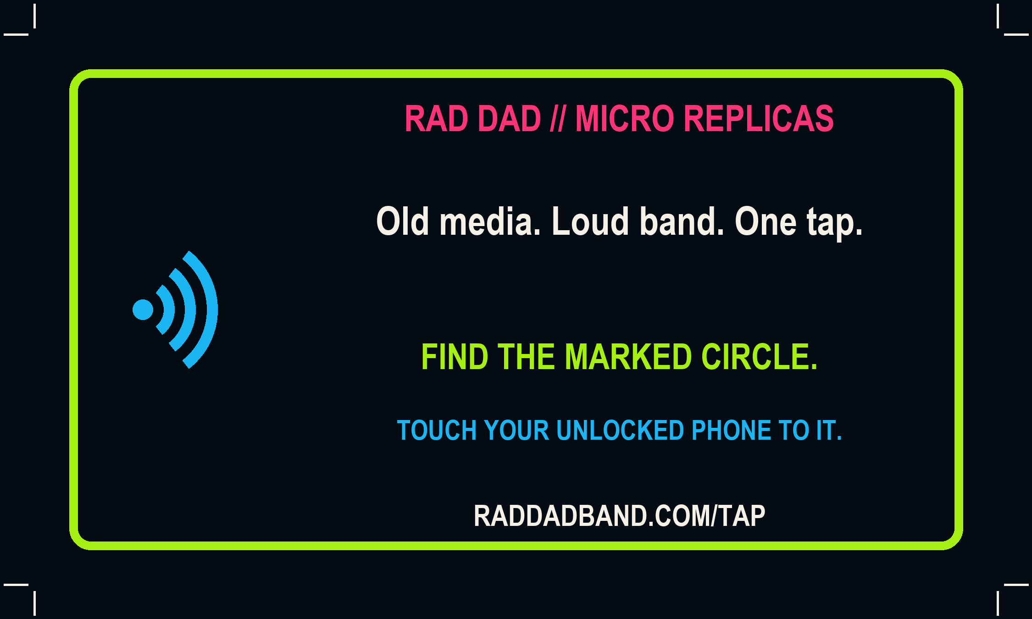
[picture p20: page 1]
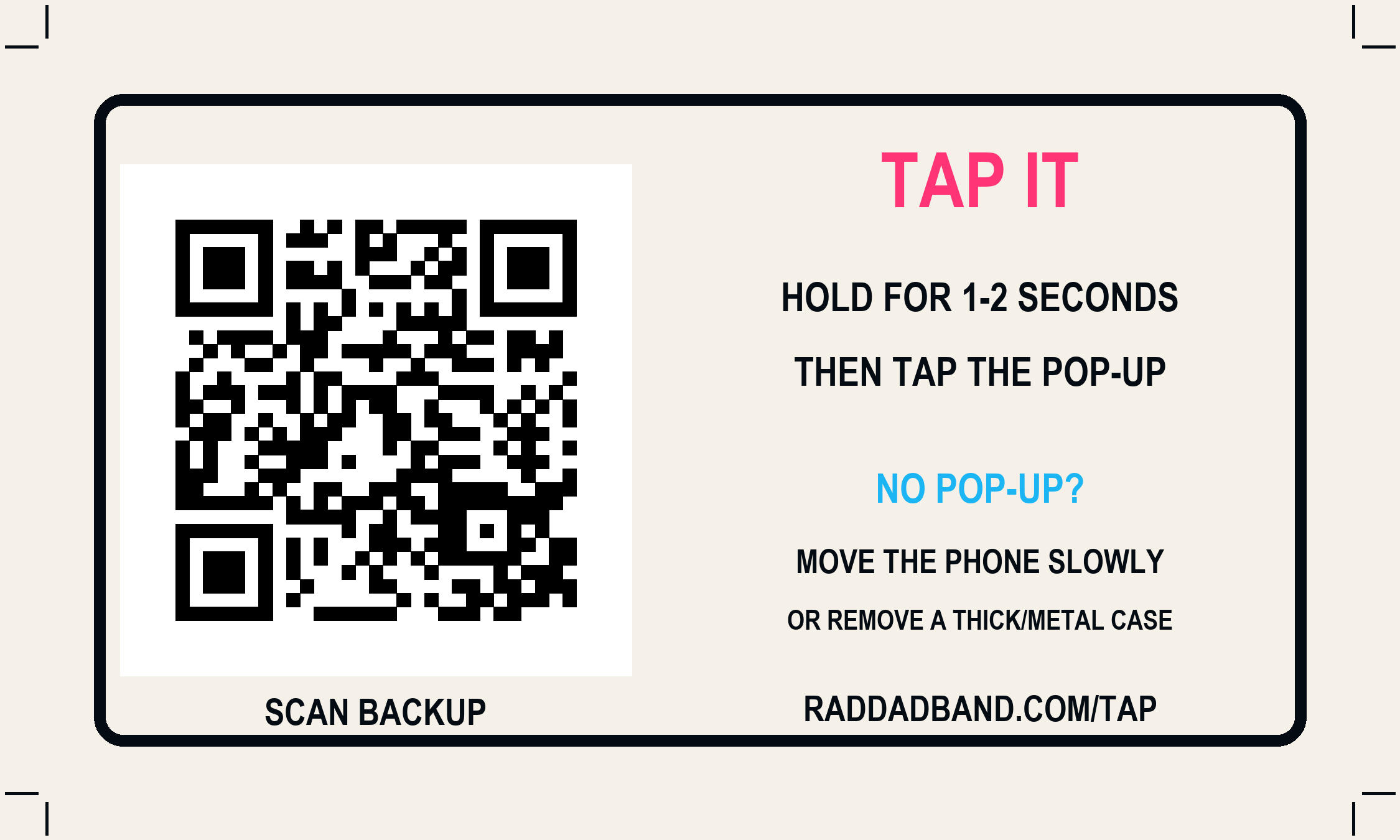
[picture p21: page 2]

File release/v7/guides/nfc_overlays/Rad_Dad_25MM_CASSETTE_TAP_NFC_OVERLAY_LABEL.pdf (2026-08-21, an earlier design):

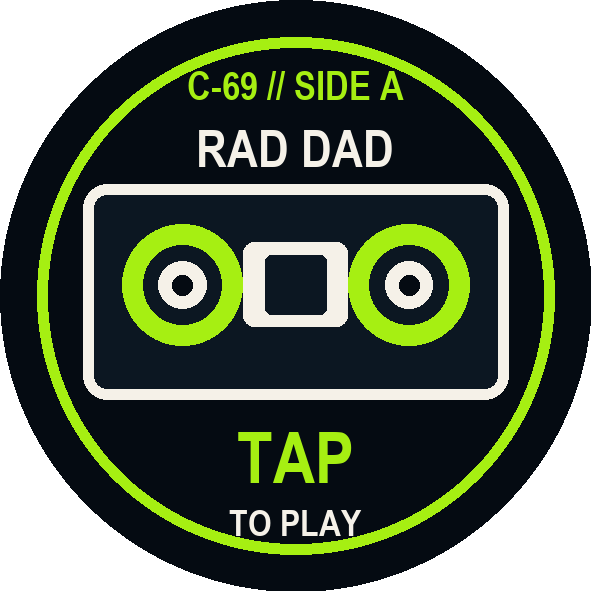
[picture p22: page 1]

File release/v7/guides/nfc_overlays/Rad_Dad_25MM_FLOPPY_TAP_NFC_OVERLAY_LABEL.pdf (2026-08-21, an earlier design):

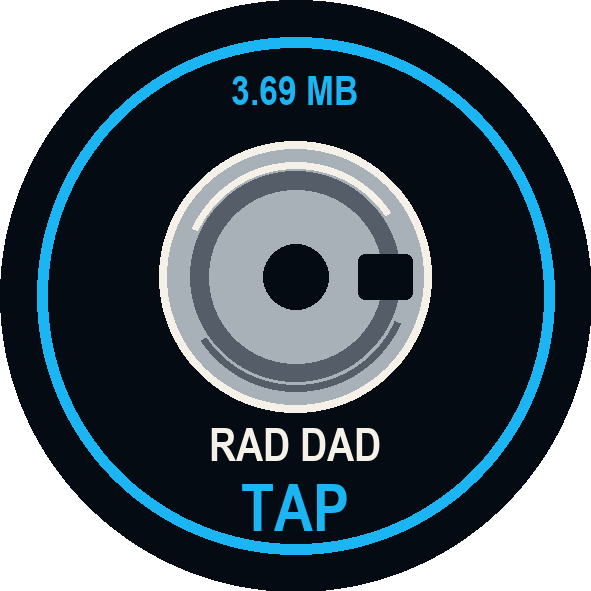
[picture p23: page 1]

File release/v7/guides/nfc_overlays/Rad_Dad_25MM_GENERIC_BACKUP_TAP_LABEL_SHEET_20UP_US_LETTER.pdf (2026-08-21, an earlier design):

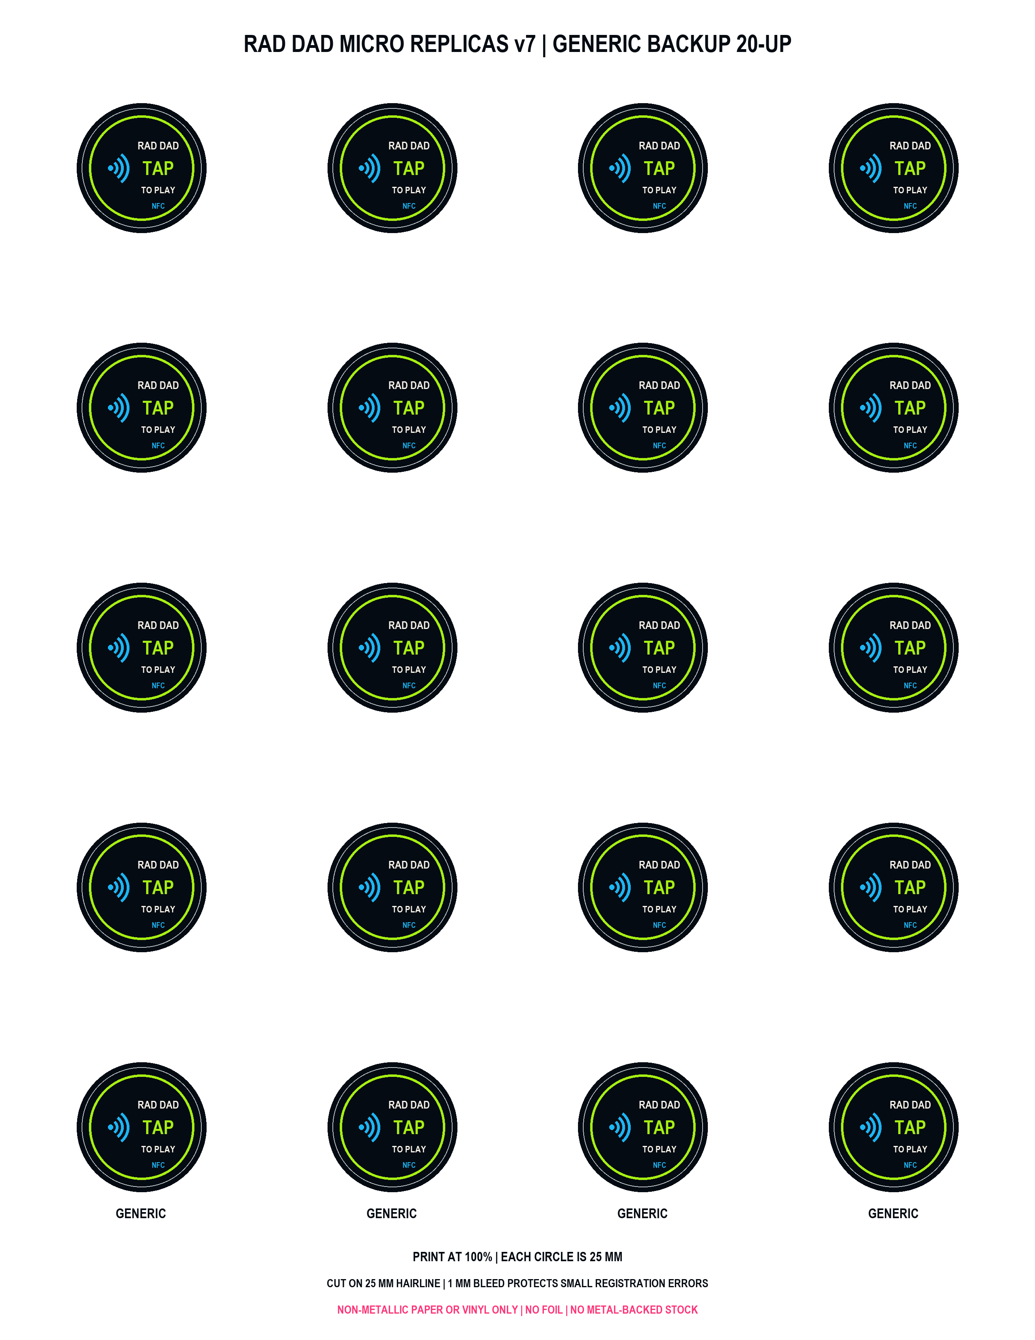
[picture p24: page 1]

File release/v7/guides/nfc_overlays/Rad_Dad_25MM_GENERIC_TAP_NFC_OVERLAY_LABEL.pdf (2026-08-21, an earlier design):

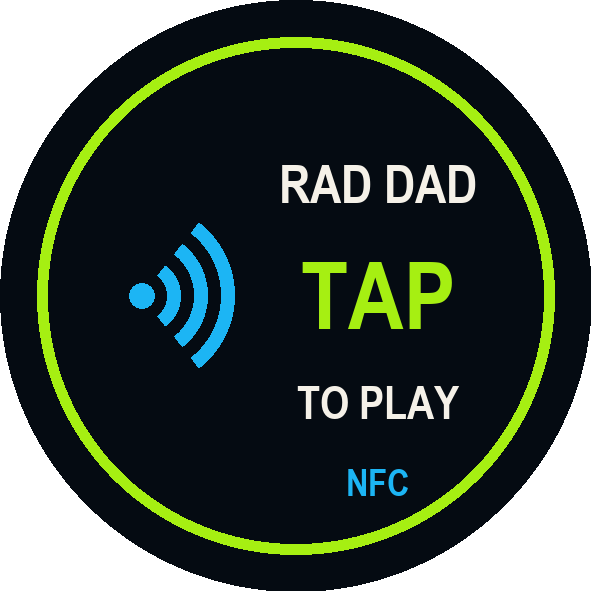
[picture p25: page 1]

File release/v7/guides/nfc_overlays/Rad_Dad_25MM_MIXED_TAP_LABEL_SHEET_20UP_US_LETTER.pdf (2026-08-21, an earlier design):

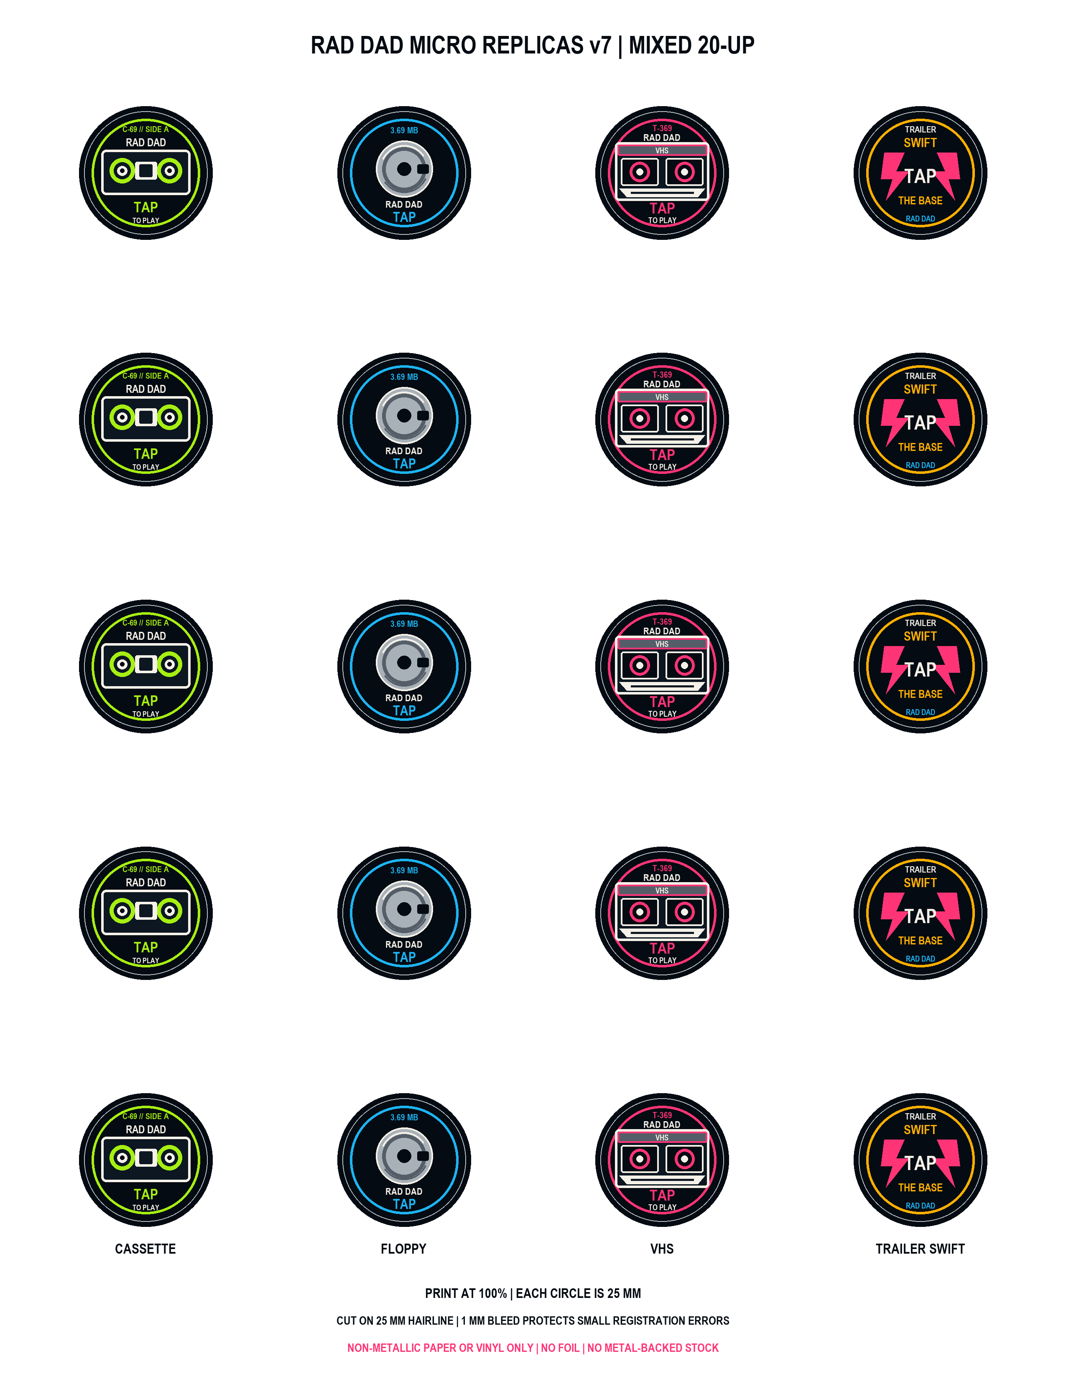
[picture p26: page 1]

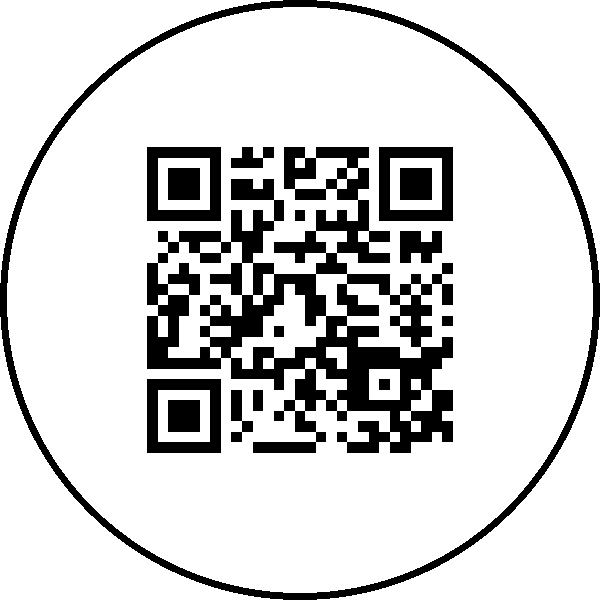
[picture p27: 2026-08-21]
release/v9/guides/qr_stickers/Rad_Dad_QR_1IN_VENDOR_MASTER_600DPI.png

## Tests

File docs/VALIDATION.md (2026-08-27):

# Rad Dad Retro Riot v9 validation plan

## Release rule

Digital QA, sliced Preview inspection, and physical validation are separate
gates. Do not describe a model as batch-ready until all applicable gates pass.

## Gate 1: automated release verification

Run from the repository root:

```bash
python3 tools/verify_v9_release.py
```

The verifier checks:

- Required v9 source, documents, QR artwork, STL, and 3MF files.
- Canonical `https://raddadband.com/qr/` metadata.
- The v22 floppy and balanced current three-device project.
- Manifest records, SHA256SUMS entries, archive checksum, and ZIP integrity.
- Bambu project generation status.
- One-body, watertight, consistently wound meshes with zero boundary,
  non-manifold, and degenerate edges.
- Exact floppy envelope and A1 Mini build-volume compliance.
- QR artwork dimensions, matrix size, quiet zone, and module pitch.

Any failure blocks release.

## Gate 2: Bambu Studio Preview

Open the configured project, slice it, and inspect every layer.

- Confirm the A1 Mini, 0.4 mm nozzle, 100% scale, and correct plate.
- Confirm media supports are off and Trailer Swift uses build-plate tree support.
- Confirm no floating, detached, or one-layer-only detail.
- Confirm all eyelet openings and QR landings remain unobstructed.
- Confirm the cassette lower transport bays are present and open.
- Confirm every character of `RAD DAD`, `3.69 MB`, `T-369`, and the Trailer
  Swift nameplate receives a continuous toolpath.
- Confirm the current three-device plate contains exactly cassette, floppy, and
  VHS with safe clearance.

Save screenshots or notes with the build record. Any unexpected slicer warning
must be understood and resolved before printing.

## Gate 3: first physical proof

Record printer, nozzle, plate, filament brand/color, drying state, slicer
version, profile, date, operator, and project filename.

### Dimensions and construction

- Measure each exterior envelope at 100% scale.
- Measure each media eyelet in two directions; nominal minimum is 6.0 mm.
- Confirm every model sits flat and every QR landing accepts a centered 25.4 mm
  sticker without edge overhang.
- Reject cracks, loose shells, open seams, exposed infill, sharp scars, strings,
  delamination, or missing details.

### Recognition

- Present each unlabelled media proof at arm's length to five unbriefed people.
- Require at least four of five to identify cassette, floppy, and VHS correctly
  within two seconds without relying on text.
- Require Trailer Swift to read as a funny punk-rock toy, not a frightening or
  unexplained shape.

### Readability

- Confirm `RAD DAD` is readable at arm's length on all media products.
- Confirm `3.69 MB` is readable at 30 cm / 12 inches in ordinary indoor light.
- Confirm `90`, `C-69`, `T-369`, `VHS`, and `TRAILER SWIFT` are complete at a
  normal handheld viewing distance.
- Inspect in bright and dim indoor light and from slight off-axis angles.

### Authentic details

- Cassette: unequal tape packs, six-lobe hubs, center window, pressure pad, and
  five real lower-edge transport bays.
- Floppy: shutter above label, orientation chamfer, front label hierarchy, rear
  spindle, shutter tracks, seam, and write-protect cue.
- VHS: wide proportions, independent reel windows, asymmetric packs, dust door,
  label, VHS marks, and rear reel-drive construction.
- Trailer Swift: friendly face, punk hair, guitar, shoes, nameplate, solid base,
  and protected underside sticker landing.

## Gate 4: keyring durability

For cassette, floppy, and VHS:

1. Install the thickest intended production split ring by hand within 30 seconds.
2. Reject any need for drilling, cutting, heating, or forced prying.
3. Apply a 2 kg static load for 60 seconds.
4. Complete 25 firm pull-and-twist cycles.
5. Drop the assembled keychain from 1 meter onto a hard floor three times in
   varied orientations.
6. Carry it with normal keys for 72 hours.
7. Reinspect bore diameter, eyelet roots, lettering, mechanical details, and
   sticker landing.

Reject whitening, cracks, permanent deformation, layer separation, or sharp
damage.

## Gate 5: QR production and installation

- Print at Actual Size / 100% on matte-white stock.
- Verify the 25.4 mm finished diameter and complete white quiet zone.
- Scan top, center, and bottom samples from every sticker batch before use.
- Require each sample to open `https://raddadband.com/qr/` on iPhone and Android.
- If using the official red fallback, print as color, confirm modules are
  pure `#FF0000` on white, and require the `Rad_Dad_QR_RED_PRINT_CALIBRATION`
  page to scan on iPhone and Android before the sheet.
- Center one sticker on the clean protected landing.
- Scan the completed item three times on each platform in indoor and outdoor
  light.
- Repeat after the drop sequence and 72-hour carry test.

Existing `/tap/` stickers pass if the permanent redirect lands at `/qr/` and the
page loads normally.

## Gate 6: release decision

Approve batch production only when:

- `tools/verify_v9_release.py` passes.
- Bambu Preview has no unexplained warnings or missing toolpaths.
- At least one current physical proof of each produced model passes.
- All measured values and test observations are recorded.
- The exact production filament, print profile, split ring, and sticker stock
  match the qualified samples.

Otherwise mark the release `HOLD`, document the defect, correct it in source,
rebuild all generated files and checksums, and repeat the affected gates.

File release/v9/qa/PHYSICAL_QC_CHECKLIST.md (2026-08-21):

# V9 physical quality-control checklist

## Sliced model

- [ ] Overall dimensions match the prior approved envelope.
- [ ] No unsupported floating islands appear in layer preview.
- [ ] Cassette transport bays are visibly open at the lower edge and align
      with the five front transport positions.
- [ ] Cassette lower ribs and rear skin remain continuous.
- [ ] Floppy reads correctly from front, edge, and rear.
- [ ] VHS reads correctly from front, edge, and rear.
- [ ] Trailer Swift face reads playful, not angry or frightening.
- [ ] Every 6 mm media eyelet accepts the thickest production split ring.

## Printed object

- [ ] First layer is complete with no lifted edge or underside tear-out.
- [ ] Fine text and molded details are readable at normal hand distance.
- [ ] No transport rib, eyelet root, guitar, hair spike, or base feature is loose.
- [ ] Trailer Swift stands without rocking.
- [ ] Representative key carry, twist, and drop checks pass.

## QR print and installation

- [ ] Calibration circle measures 25.4 mm and reference square measures 50 mm.
- [ ] QR modules are square, solid black, and surrounded by uninterrupted white.
- [ ] If using the fallback, modules are solid pure red on clean white and the
      printer is set to color rather than grayscale.
- [ ] Top, center, and bottom sheet samples scan before cutting.
- [ ] Sticker is centered, flat, clean, and fully adhered.
- [ ] Installed QR opens `https://raddadband.com/qr/` on iPhone and Android.
- [ ] Indoor light, bright overhead light, and daylight all pass.
- [ ] Final scan passes again after a 24-hour adhesive cure.

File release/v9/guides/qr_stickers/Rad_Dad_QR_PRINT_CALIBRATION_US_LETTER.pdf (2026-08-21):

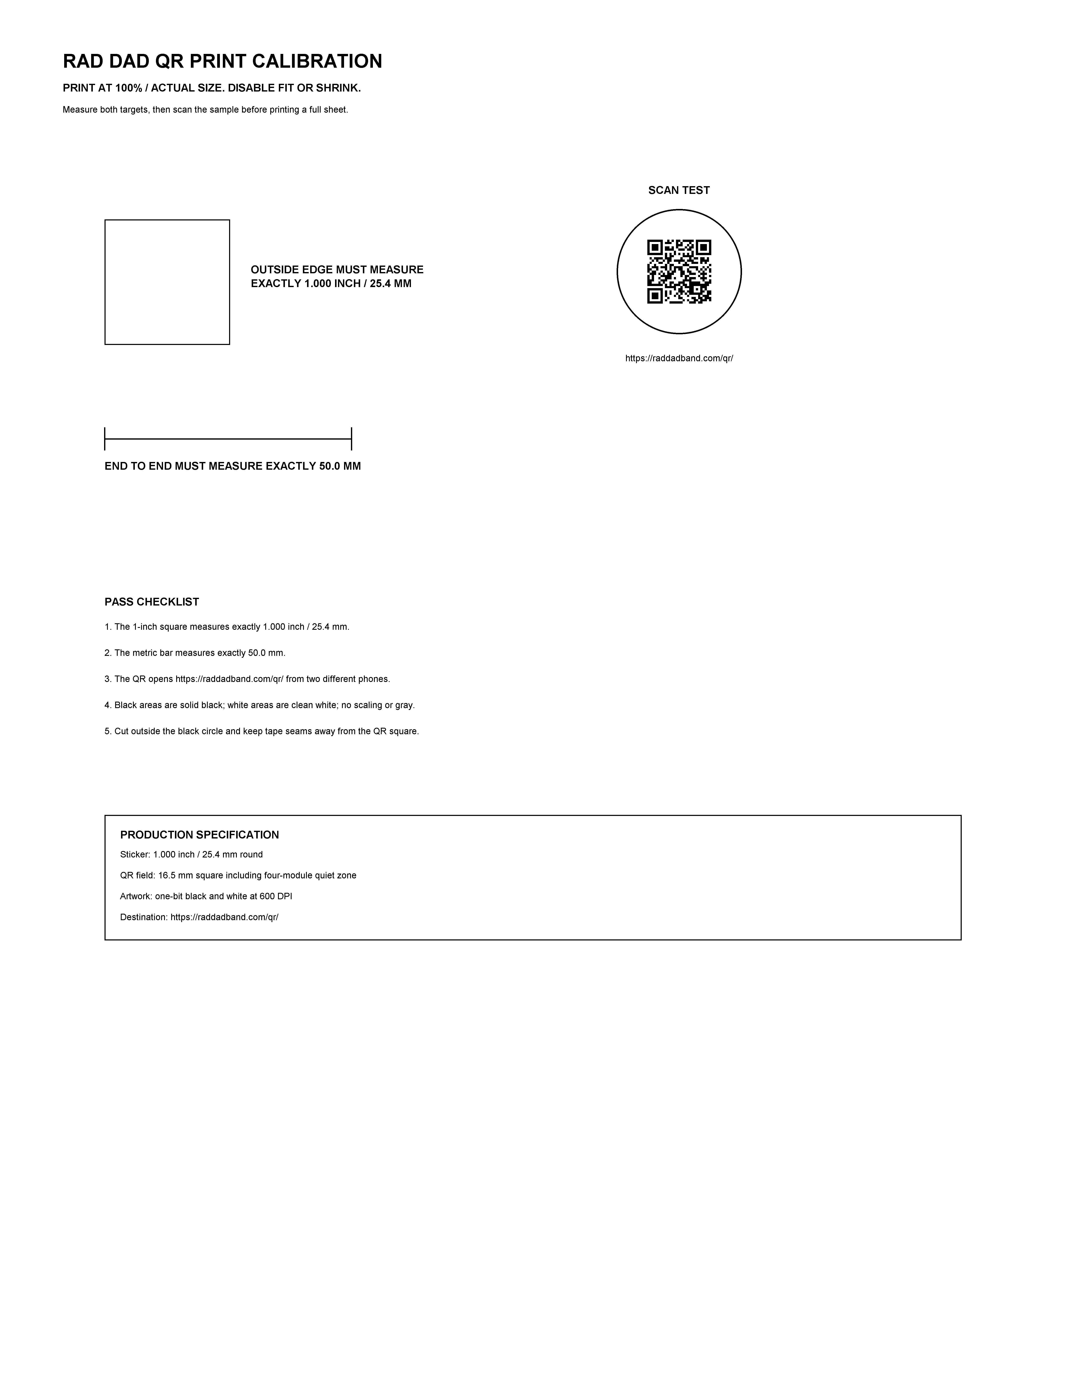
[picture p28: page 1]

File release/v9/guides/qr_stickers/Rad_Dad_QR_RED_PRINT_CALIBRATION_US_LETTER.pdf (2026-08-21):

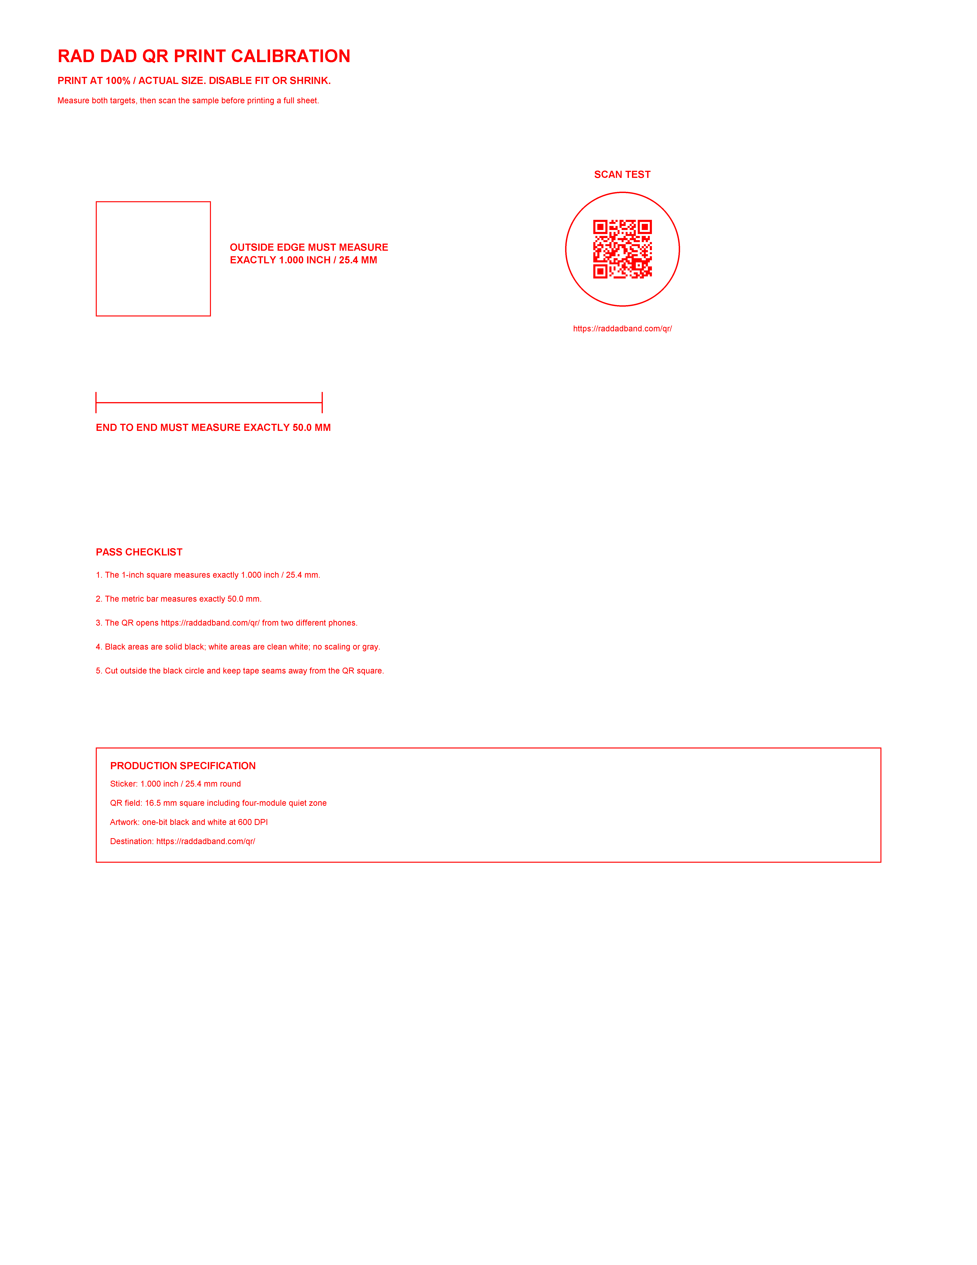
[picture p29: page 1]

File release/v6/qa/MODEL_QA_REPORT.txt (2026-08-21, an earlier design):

RAD DAD RETRO RIOT v6 - DIGITAL QA

Rad Dad Cassette v36
  Watertight: True
  Winding consistent: True
  Boundary edges: 0
  Non-manifold edges: 0
  Bodies: 1
  Dimensions: 60.324 x 30.260 x 6.685 mm
  Volume: 7307.021 cubic mm

Rad Dad Floppy v18
  Watertight: True
  Winding consistent: True
  Boundary edges: 0
  Non-manifold edges: 0
  Bodies: 1
  Dimensions: 46.560 x 36.916 x 4.130 mm
  Volume: 4290.458 cubic mm

Rad Dad Mini VHS v3
  Watertight: True
  Winding consistent: True
  Boundary edges: 0
  Non-manifold edges: 0
  Bodies: 1
  Dimensions: 70.000 x 32.600 x 5.500 mm
  Volume: 9096.710 cubic mm

Trailer Swift v4 Bobblehead NFC
  Watertight: True
  Winding consistent: True
  Boundary edges: 0
  Non-manifold edges: 0
  Bodies: 1
  Dimensions: 53.000 x 53.000 x 80.460 mm
  Volume: 26151.945 cubic mm

Release checks:
  Physical objects on combined plate: 4
  Media keyring openings: 6.00 mm nominal
  Trailer Swift format: upright solid-base desk collectible
  NFC diameter: 25.00 mm nominal on all four designs
  Floppy rear NFC protected radius: 12.85 mm
  Trailer Swift base: 53.00 mm maximum diameter
  Combined plate footprint: 145.500 x 127.800 mm
  Combined plate bounds: X 15.500 to 161.000; Y 16.500 to 144.300
  Fits A1 Mini XY: True
  Physical print validation: REQUIRED BEFORE BATCH PRODUCTION

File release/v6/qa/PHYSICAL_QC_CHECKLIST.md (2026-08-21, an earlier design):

# Retro Riot v6 physical quality-control checklist

Record filament, printer, nozzle, plate, date, and operator for every test batch.

## Identity and finish

- [ ] Cassette reads immediately as a compact cassette at arm's length.
- [ ] Floppy front and rear read immediately as a 3.5-inch disk.
- [ ] VHS reads immediately as VHS, not as a cassette.
- [ ] Trailer Swift stands squarely and the front nameplate is readable.
- [ ] RAD DAD and 3.69 MB are complete and legible.
- [ ] No strings, gaps, elephant foot, loose details, or sharp cleanup scars.

## Function

- [ ] Every media eyelet accepts the thickest production split ring.
- [ ] Every eyelet survives ten firm pull-and-twist cycles.
- [ ] Every programmed NFC tag scans before installation.
- [ ] Every installed tag scans three times on iPhone and three times on Android.
- [ ] TAP TO PLAY label remains fully adhered around its circumference.
- [ ] Trailer Swift base does not rock after the NFC tag is installed.

## Durability

- [ ] Each design survives a one-meter drop onto a hard floor three times.
- [ ] Media samples complete three days of pocket/key carry without eyelet damage.
- [ ] Trailer Swift hair, guitar, feet, and base remain intact after handling.

## Release decision

- [ ] PASS: approved for batch production.
- [ ] HOLD: defect documented and corrected before reprint.

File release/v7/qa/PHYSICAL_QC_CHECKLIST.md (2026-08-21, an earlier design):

# Micro Replicas v7 physical quality-control checklist

Record printer, nozzle, filament, plate, slicer version, profile, date, tag
vendor/SKU/lot, overlay stock, split ring, phone models, and operator.

## Identity and finish

- [ ] Cassette reads immediately as a compact cassette at arm's length.
- [ ] Floppy front and rear read immediately as a 3.5-inch disk.
- [ ] VHS reads immediately as VHS, not as an audio cassette.
- [ ] Trailer Swift reads as a three-dimensional bobblehead-style punk figure.
- [ ] RAD DAD, C-69, 3.69 MB, T-369, and TRAILER SWIFT are readable.
- [ ] No strings, gaps, unsupported damage, loose details, or sharp scars.

## Mechanical function

- [ ] Every media eyelet accepts the thickest production split ring easily.
- [ ] Every eyelet survives a 2 kg static load for 60 seconds.
- [ ] Every eyelet survives 25 firm pull-and-twist cycles.
- [ ] Each media piece survives one-meter drops in six orientations.
- [ ] Each media piece completes at least 72 hours of representative key carry.
- [ ] Trailer Swift stands without rocking and survives normal desk handling.

## NFC function

- [ ] Loose tag scans before encoding and after encoding.
- [ ] Installed tag scans ten consecutive times on iPhone.
- [ ] Installed tag scans ten consecutive times on Android.
- [ ] Tag scans after the overlay is applied and after 24-hour adhesive cure.
- [ ] Tag scans with a normal phone case and with the production split ring fitted.
- [ ] Overlay remains fully adhered and does not rub directly on a tabletop.

## Slicer and release gate

- [ ] File type is recorded as model-only Core 3MF or true Bambu project 3MF.
- [ ] A1 Mini and 0.4 mm nozzle profiles are explicitly selected.
- [ ] Individual cassette, floppy, and VHS projects have supports off.
- [ ] The individual Trailer Swift project uses organic build-plate-only supports.
- [ ] The all-four project uses global `tree(auto)`, build-plate-only supports.
- [ ] Combined-project Preview confirms no unnecessary cassette, floppy, or VHS supports.
- [ ] Every sliced layer is reviewed before printing.
- [ ] PASS: approved for batch production.
- [ ] HOLD: defect documented and corrected before reprint.

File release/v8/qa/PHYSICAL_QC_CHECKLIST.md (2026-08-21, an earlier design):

# V8 QR Edition physical quality-control checklist

Record printer, nozzle, filament, plate, slicer version, sticker stock, printer
used for labels, date, phone models, split ring, and operator.

## Printed object

- [ ] Cassette, floppy, and VHS are recognizable within two seconds.
- [ ] Trailer Swift stands without rocking.
- [ ] `RAD DAD`, `C-69`, `3.69 MB`, `T-369`, and `TRAILER SWIFT` are readable.
- [ ] No gaps, strings, sharp scars, loose details, or underside damage.
- [ ] Every media eyelet accepts the thickest production split ring easily.
- [ ] Required load, twist, drop, and carry tests are complete.

## Sticker production

- [ ] Calibration circle measures 25.4 mm / 1.000 inch.
- [ ] Calibration square measures 50.0 mm.
- [ ] Page was printed at Actual Size / 100% with automatic scaling disabled.
- [ ] Black modules are solid, square, and free of streaks or toner voids.
- [ ] White quiet zone is clean and uninterrupted.
- [ ] Top, center, and bottom sheet samples scan before installation.

## Finished product scan gate

- [ ] Sticker is centered inside the model's circular landing.
- [ ] Sticker edge is fully adhered with no bubbles, wrinkles, or lifted edge.
- [ ] Finished piece opens `https://raddadband.com/tap/` on iPhone.
- [ ] Finished piece opens `https://raddadband.com/tap/` on Android.
- [ ] Both phones pass with ordinary protective cases installed.
- [ ] Indoor light and bright daylight both pass.
- [ ] Scan passes again after 24-hour adhesive cure.
- [ ] Keychain pieces pass after split-ring installation and representative keys are attached.
- [ ] PASS: approved for distribution.
- [ ] HOLD: defect documented and corrected before rework or reprint.

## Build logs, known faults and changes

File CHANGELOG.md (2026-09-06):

# Changelog

## Digital merch desk

- Cart updates now show pending, success, rejection, and uncertain outcomes.
  Pending changes pause other cart edits and hold submission. Lost responses
  never trigger another mutation; an explicit current-cart link provides
  recovery. Quantity-button intent and native no-JavaScript forms are preserved.

- Added **Your holds** navigation with the current session's receipts, newest
  first, and explicit confirmed withdrawal from each active receipt. Withdrawn
  status is shared with the admin desk; retries keep the first withdrawal time.
- Kept receipt details after withdrawal and stated the in-memory/session access
  limits. Added owner-isolation, CSRF, confirmation, retry, and lifecycle tests.

- Catalog cards and product pages now serve leftover-#8 crops of the Current
  Three study so cassette, floppy, and mini VHS are visually distinct on a
  phone. Combined study stays the original render bytes.
- Checkout requires an explicit digital-hold confirmation and redirects to a
  session-owned receipt. Empty carts still have no checkout. Nothing is priced,
  charged, printed, shipped, or posted.
- Hold-cart quantity uses 44 px steppers instead of a cramped number field.

- Added a shopper catalog, cart, and request-hold flow bound to the leftover
  Current Three PETG material study.
- Added an admin publish/hold desk with token auth, CSRF, and rate-limited
  sign-in. Unpublished cards leave the public catalog and cannot enter a cart.
- Locked the public merch path to an allowlist so STL, 3MF, renderer, and
  release files are not served as shop assets. Checkout rejects shipping,
  payment, printer, and pitch fields.
- Added `tools/serve_digital_merch.py`, `tools/verify_digital_merch.py`, and a
  release-integrity CI step. No prices, print jobs, QR destination change, or
  merch auto-post.

## Current Three material-study preview

- Added a dedicated cassette v38, floppy v22, and mini VHS v5 overview rendered
  directly from the current sealed STL files at true relative scale.
- Reused the existing software-rendering conventions while adding restrained
  satin-PETG shading, specular response, grounded shadows, and a 25 mm reference
  without altering printable geometry or the sealed v9 package.
- Added machine-readable source/output/renderer provenance and a CI smoke render
  that fails closed if the preview loses its digital-only disclaimer.

## Trailer Swift v16 Strat-style guitar rebuild

- Replaced the generic double-cutaway with a rounded Strat-style perimeter:
  long upper horn, short lower horn, narrow waist, offset shoulder, and broad
  lower bout.
- Rebuilt the front as a recognizable SSS layout with an angled bridge pickup,
  full pickguard, synchronized tremolo block and arm, three knobs, five-way
  blade switch, jack cup, bridge saddles, position dots, and strap buttons.
- Replaced the generic three-per-side headstock with an asymmetric six-inline
  profile, six same-side tuners, string tree, tapered neck, nut, and two durable
  representative strings.
- Kept the design unbranded while preserving the v15 face, clean jeans, exact
  45 x 45 x 64.4 mm envelope, one-piece construction, and 27 mm QR landing.

## Trailer Swift v15 expression and instrument refinement

- Opened the eyes, thinned and raised the lids, and reduced the brows so the
  expression reads alert and musical rather than sleepy.
- Replaced the mustache-like split tooth bars with one recessed curved tooth
  mass and simplified the tongue and lower lip inside the singing mouth.
- Rounded the guitar body perimeter, added a printable fretboard nut, preserved
  its aligned hardware and strap, and removed the unrealistic external flame
  tabs while retaining the flame relief on the body.
- Preserved the clean jeans, exact 45 x 45 x 64.4 mm envelope, one-piece
  construction, and full 27 mm underside QR landing.

## Trailer Swift v14 face and guitar realism pass

- Rebuilt the eyes as inset eyeballs with raised irises and printable upper lids
  instead of empty sockets with floating dots.
- Reshaped the nose and singing mouth with a smaller cavity, sloped upper teeth,
  recessed tongue, lower lip, and cheek creases.
- Broadened the double-cutaway guitar body, added a connected shoulder strap,
  retained aligned strings and hardware, and reduced the rear flames from three
  spikes to two smoother attached flame forms.
- Preserved the clean v13 jeans, exact 45 x 45 x 64.4 mm envelope, one-piece
  construction, and full 27 mm underside QR landing.

## Trailer Swift v13 source-level jeans rebuild

- Removed the complete three-stroke plaid generator responsible for the star
  shapes instead of attempting to filter its geometry after assembly.
- Rebuilt each pant leg with one stance-following outside seam and one durable
  molded cuff line above the boot.
- Retained the v11 retail-style face, hair, flaming guitar, two-line nameplate,
  exact 45 x 45 x 64.4 mm envelope, and full 27 mm underside QR landing.

## Trailer Swift v12 retail cleanup

- Removed the crossed star stitching from both jean legs so the clothing reads
  as a clean molded toy rather than a themed costume.
- Preserved the smoother expressive head, asymmetric punk hair, flaming guitar,
  two-line display name, exact 45 x 45 x 64.4 mm envelope, and 27 mm QR landing.
- Kept the figurine as one connected, watertight, support-ready collectible.

## 2026-08-11 - Trailer Swift retail-toy redesign

- Advanced Trailer Swift to v11 with a smoother designer-toy head, asymmetric
  upward flame hair, narrower expressive eye sockets, a simplified singing
  face, and a two-line retail nameplate that can be read in one color.
- Added three structural flame tongues to the electric-guitar silhouette and
  retained the large shirt bolt, plaid pants, punk stance, and album-character
  cues so the result feels like Jeff without becoming a literal portrait.
- Kept the exact 45 x 45 x 64.4 mm envelope and protected 27 mm underside QR
  landing. Cassette, floppy, VHS, keyring, and plate geometry are unchanged.

## 2026-08-11 - Physical-readability pass

- Advanced the floppy to v22 after PETG testing showed the v21 `3.69 MB`
  mark was still too small. The mark is now centered, 20.00 x 4.00 mm, and uses
  substantially heavier stroke geometry without changing the disk envelope.
- Advanced Trailer Swift to v10 with deep eye and mouth shadows, anchored inset
  pupils, simplified plaid, a larger shirt bolt, stronger guitar relief, and a
  heavier base name so the character reads clearly as a punk guitarist.
- Preserved the 45 x 45 x 64.4 mm figurine envelope, 27 mm underside QR landing,
  floppy keyring bore, cassette/VHS geometry, and all established plate layouts.

## v9.1 - Floppy Capacity Legibility - 2026-08-11

- Advanced the 3.5-inch floppy from v20 to v21 after physical-print feedback
  showed that the lower-right `3.69 MB` capacity mark was too difficult to read.
- Increased the mark from 10.20 x 2.30 mm to 12.60 x 2.85 mm, strengthened the
  bold stroke geometry, and moved it slightly inward for cleaner label spacing.
- Kept the exact `44.360 x 36.916 x 4.130 mm` envelope, 6.0 mm keyring bore,
  shutter, label hierarchy, rear mechanics, and 25.4 mm QR landing unchanged.
- Updated the release builder, printing guidance, validation gate, and current
  three-device plate workflow for the v21 floppy.

## v9 - Authenticity + QR Edition - 2026-08-09

### Authenticity restoration

- Promoted v9 as the recommended production release while preserving v8 and v7
  as historical QR and NFC archives.
- Advanced the compact cassette to v38 using the exact watertight v36 body that
  produced the successful physical reference print. Its narrow tape-entry edge,
  stepped shell, and asymmetric head, capstan, guide, and pinch-roller apertures
  are inherited directly rather than reconstructed as face decoration.
- Moved only the cassette eyelet zone inward to the approved compact envelope.
  The deformation is zero at the tape-entry edge, preserving that audited
  transport geometry while retaining the proven 6 mm bore and rear landing.
- Advanced the 3.5-inch floppy to v20 with deeper rear hub, shutter-track,
  shell-seam, write-protect, and density cues around the existing circular QR
  landing.
- Advanced the mini VHS to v5 with stronger reel, tape-path, door, latch,
  insertion, shell, and rear-device cues around the existing circular QR
  landing.
- Advanced Trailer Swift to v6 with friendlier eyes, relaxed brows, and a goofy
  singing grin so the character reads as funny and punk rather than angry or
  scary.
- Preserved the collection details `C-69`, `3.69 MB`, and `T-369` without
  allowing the easter eggs or Rad Dad branding to replace defining hardware.

### Fit and construction

- Kept all four external envelopes unchanged: cassette
  `58.162 x 30.260 x 6.685 mm`, floppy `44.360 x 36.916 x 4.130 mm`, VHS
  `65.800 x 31.900 x 7.000 mm`, and Trailer Swift
  `45.000 x 45.000 x 64.400 mm`.
- Kept the reinforced cassette, floppy, and VHS keyring eyelets and their 6 mm
  openings unchanged.
- Kept the protected 26 mm media landings and 27 mm Trailer Swift base landing
  unchanged for exact 25.4 mm / 1-inch QR stickers.
- Confined the authenticity work to the existing product envelopes so v9 does
  not increase pocket bulk, plate usage, or keyring reach.

### Black-and-white QR production

- Replaced the colored/styled sticker presentation with strictly black-and-white
  QR artwork on matte white adhesive stock.
- Preserved a 29 x 29 error-correction-Q matrix, four-module white quiet zone,
  16.5 mm printed QR square, and approximately 0.446 mm module pitch.
- Added individual vendor masters, an exact 63-up US Letter sheet for Avery
  6450 and OnlineLabels OL1025, and a dedicated FedEx Office full-sheet file.
- Standardized all print instructions on Actual Size / 100% with fit-to-page,
  shrinking, enlargement, and photo optimization disabled.
- Required physical measurement and scan QC before cutting, after installation,
  after adhesive cure, and before distribution.
- Set the generated release archive path to
  `release/v9/Rad_Dad_Retro_Riot_v9_Authenticity_QR_Print_Pack.zip`.
- Retained NFC documentation only as a legacy reference; NFC is not part of the
  recommended v9 production workflow.

## v8 - QR Edition - 2026-08-09

- Replaced the production NFC workflow with one visible 1-inch QR sticker.
- Preserved every v7 STL and 3MF byte-for-byte; no model was resized or remodeled.
- Added a scan-first black-and-white QR for `https://raddadband.com/tap/` with
  error correction Q, four-module quiet zone, and approximately 0.446 mm modules.
- Added vendor-ready SVG, 600 DPI PNG, and exact-size PDF artwork.
- Added an exact 63-up US Letter sheet for Avery 6450 and OnlineLabels OL1025.
- Added a 35-up hand-cut sheet, print calibration page, placement guide,
  sourcing guide, installation guide, and QR-specific physical QC checklist.
- Added model-reuse provenance, v7 geometry evidence, manifest, SHA-256 sums,
  deterministic release ZIP, and automated v8 integrity verification.
- Marked the v7 NFC release as a historical archive rather than deleting it.

## 0.4.0 - 2026-08-09 - Retro Riot v7: Micro Replica Edition

### Final products

- Finalized four one-color micro replicas: Rad Dad Compact Cassette v37, Rad
  Dad 3.5-Inch Floppy v19, Rad Dad Mini VHS v4, and Trailer Swift v5 Punk Desk
  Toy.
- Preserved the compact cassette, floppy, and VHS envelopes while exaggerating
  defining mechanical details enough to remain recognizable at keychain scale.
- Kept `RAD DAD` prominent without replacing the hardware that identifies each
  original format.

### Authenticity and construction

- Rebuilt the cassette face with unequal tape packs, broad six-lobe drive hubs,
  a deeper center tape window, five clean blind transport recesses, a visible
  pressure pad, shell hardware, and a restrained `C-69` marking alongside the
  traditional `90` designation.
- Reworked the floppy with a dominant upper shutter, writable label treatment,
  write-protect and density details, developed front and rear shell features,
  and the readable `3.69 MB` capacity joke.
- Replaced the VHS's cassette-like shared reel treatment with separate reel
  windows, six-rib hubs, visible tape coils, a central label zone, a
  full-width dust cover, latch, insertion arrow, `VHS` mark, and `T-369` detail.
- Rebuilt Trailer Swift as a one-piece, three-dimensional punk collectible with
  an oversized expressive head, flame-shaped hair, short toy proportions,
  broad shoes, faux spring neck, an integrated angular electric guitar, rear
  vest and strap detail, a readable two-line nameplate, and a 45 mm circular
  display base.
- Added a protected 25 mm NFC landing beneath the Trailer Swift base with an
  annular bed-contacting rim, keeping the tag off the table without fragile
  perimeter feet.

### Keyrings and NFC experience

- Standardized the cassette, floppy, and VHS on reinforced integrated eyelets
  with 6 mm openings and substantial material around each bore.
- Preserved flat rear NFC landings on all three media keychains so the 25 mm tag
  does not obscure their authentic front details.
- Standardized all four products on nonmetal 25 mm NFC tags encoded to the live
  `https://raddadband.com/tap/` landing page.
- Added product-specific nonmetal overlays for cassette, floppy, VHS, and
  Trailer Swift, plus mixed and backup 20-up label sheets in PNG, SVG, and PDF
  formats.
- Added front-and-back handoff-card artwork with a marked-circle instruction,
  phone-tapping guidance, and a QR fallback for the live landing page.
- Added the cross-format `C-69`, `3.69 MB`, and `T-369` easter egg while leaving
  Trailer Swift focused on the character and nameplate.

### Print and release tooling

- Generated individual binary STL files, model-only 3MF packages, and true
  Bambu Studio A1 Mini 0.4 mm project 3MF files for all four products.
- Added the one-print Retro Riot v7 all-four A1 Mini project with exactly four
  objects, at least 10 mm spacing, flat media orientation, and upright Trailer
  Swift placement.
- Standardized the starting profile at 0.16 mm layers, four walls, five top and
  bottom layers, 30% gyroid infill, supports off for the media models, and
  build-plate-only organic support for Trailer Swift.
- Added reproducible v7 model, Bambu-project, preview, label, guide, manifest,
  checksum, and release-archive generation from pinned Python dependencies.
- Added structured product metadata, print intents, mesh QA, plate-layout
  records, physical-QC checklists, a strict release validator, and CI coverage
  for automated release-integrity checks.
- Matched every embedded quality profile to the documented 30 mm/s outer and
  top-surface speeds, 25 mm/s small-perimeter speed, and rear seam placement.
- Added oblique product renders, explicit NFC-landing callouts, one-millimeter
  sticker bleed, true 25 mm cut guides, and a VHS-specific overlay treatment.

### Validation boundary

- Digital mesh checks confirm that the four generated models are finite,
  single-body, watertight, consistently wound, manifold, nondegenerate, and
  within the A1 Mini build volume.
- The strict release gate reports 217 passes, zero warnings, and zero critical
  failures, including successful Bambu Studio CLI slicing of all ten 3MF files.
- V7 remains a physical-test release candidate rather than an approved batch
  product. Ring installation, pull and twist, drop, pocket carry, surface
  finish, Trailer Swift stability, sticker adhesion, and repeated iPhone and
  Android NFC tests must pass with the actual production filament, tags,
  overlays, and split rings before batch production.

## 0.3.0 - 2026-08-09

- Rebuilt the mini VHS as v3 with an unmistakable hinged tape-door band,
  framed reel bay, nine-tooth hubs, center tape gauge, five screw positions,
  and restrained label treatment.
- Reworked the floppy as v18 with a developed rear shell seam, hub boundary,
  shutter track, write-protect detail, and preserved 25 mm NFC contact zone.
- Replaced the flat Trailer Swift charm with the v4 upright punk collectible.
- Added a solid stepped circular display base, integrated nameplate, toy-like
  body depth, faux bobble spring, and underside NFC placement guide.
- Added individual test plates and the Retro Riot v6 four-piece A1 Mini plate.
- Added reproducible source, documentation, release checksums, and automated
  repository integrity checks.
- Added a 25 mm `TAP TO PLAY` NFC label, a 20-up letter-size label sheet, and a
  handoff card so tap behavior is obvious without compromising the authentic
  media fronts.
- Added a molded `TAP THE BASE` cue to the Trailer Swift display stand.
# Repository rename and authenticity micro-refinement pass

- Refined Trailer Swift v16 with a slimmer cocked head, layered eyelids, smile and ear folds, a broad singing grin, molded boot laces, pickup pole pieces, and pickguard fasteners while retaining the exact envelope, pose, base, and underside QR landing.
- Moved the full `3.69 MB` marking into the clear shell field directly below the floppy label while preserving its high-contrast size and stroke weight.
- Added shallow, asymmetric write-protect and density-detection recesses to the floppy front without opening the shell or disturbing its rear QR landing.
- Renamed the project from `Rad-Dad-NFC-Tags` to `Rad-Dad-QR-Merch` so the repository identity matches the current QR-first merchandise collection.
- Kept the approved cassette geometry unchanged, including its audited tape-transport edge, proportions, QR land, and compact eyelet.
- Added subtle stamped shutter lips and a slide-direction mark to the floppy without changing its dimensions, label, `3.69 MB` marking, QR land, or key-ring geometry.
- Added molded concentric reel rings and restrained flip-up door ribs to the VHS without changing its dimensions, larger `RAD DAD` label, QR land, or key-ring geometry.
- Preserved Trailer Swift's established collectible silhouette, clean jeans, Strat-style guitar, base, and underside QR land rather than risking another broad redesign.

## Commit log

2026-08-09 feat: add Retro Riot v6 NFC collection
    [Rad_Dad_Cassette_v36.stl, Rad_Dad_Cassette_v36_SINGLE_TEST_A1_MINI.3mf, Rad_Dad_Floppy_v18.stl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]
2026-08-09 feat: ship Retro Riot v7 micro replicas
    [Rad_Dad_Cassette_v37_A1_MINI_0.4_PROJECT.3mf, Rad_Dad_Cassette_v37_BINARY.stl, Rad_Dad_Cassette_v37_MODEL_ONLY.3mf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]
2026-08-09 feat: ship v9 authenticity QR release
    [Rad_Dad_Cassette_v36_COMPACT_WIDE_WIRE_EYELET_BODY.stl, Rad_Dad_Cassette_v37_A1_MINI_0.4_PROJECT.3mf, Rad_Dad_Cassette_v37_BINARY.stl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]
2026-08-10 feat: add support-ready v9 release and red QR sheets
    [Rad_Dad_Cassette_v33_FINAL_AUDITED_BODY.stl, Rad_Dad_Retro_Riot_v9_ALL_FOUR_A1_MINI_0.4_TREE_SUPPORT_PROJECT.3mf, Rad_Dad_Retro_Riot_v9_ALL_FOUR_MODEL_ONLY.3mf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]
2026-08-11 Use canonical QR landing URL
2026-08-11 Improve floppy capacity legibility and rebuild v9
    [Rad_Dad_Cassette_v38_A1_MINI_0.4_PROJECT.3mf, Rad_Dad_Floppy_v20_BINARY.stl, Rad_Dad_Floppy_v20_MODEL_ONLY.3mf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]
2026-08-11 Rename project and publish authentic QR merch v9
    [Rad_Dad_Cassette_v38_A1_MINI_0.4_PROJECT.3mf, Rad_Dad_Floppy_v21_A1_MINI_0.4_PROJECT.3mf, Rad_Dad_Floppy_v21_BINARY.stl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]
2026-08-11 Refine floppy capacity placement and three-item release
    [Rad_Dad_Cassette_v38_A1_MINI_0.4_PROJECT.3mf, Rad_Dad_Floppy_v22_A1_MINI_0.4_PROJECT.3mf, Rad_Dad_Floppy_v22_BINARY.stl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]
2026-08-12 Refine Trailer Swift singing collectible
    [Rad_Dad_Cassette_v38_A1_MINI_0.4_PROJECT.3mf, Rad_Dad_Floppy_v22_A1_MINI_0.4_PROJECT.3mf, Rad_Dad_Mini_VHS_v5_A1_MINI_0.4_PROJECT.3mf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]
2026-08-27 Align current merch/QR docs with live model revisions (#4)
    The current-model tables still named floppy v21 and Trailer Swift v9 after
    those models advanced, and the printing guide pointed at a retired v9 3MF.
    Match the live v9 metadata and gate the leftover with a docs verifier.
2026-08-27 Document official red QR fallback in current merch docs (#5)
    Docs match already-shipped v9 red fallback. No new merch, no #2.
2026-09-03 feat: add honest current-three material study (#8)
    Made-with: Codex Extra High
2026-09-05 Add digital merch desk after leftover #8 (#9)
    * feat: add digital merch desk for leftover Current Three study
    Give shoppers a catalog, cart, and request-hold flow bound to the
    leftover #8 PETG material study, and give admin a publish/hold desk.
    Keep the public merch path on an allowlist so print files, renderer
    paths, and spend/shipping fields stay off the shop.
    * fix: tighten digital merch shopper UX and public admin exposure
    Hide the admin link from unsigned public nav, give each Current Three
    card its own study copy, and replace the empty-cart checkout form with
    a browse CTA so a held request cannot be submitted again.
    Co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
2026-09-05 Make merch catalog identifiable and hold receipts durable (#10)
    * Make merch catalog identifiable and hold receipts durable
    Crop the leftover Current Three study so cassette, floppy, and VHS cards
    are distinct on a phone. Require an explicit digital-hold confirmation,
    then keep a session-owned receipt instead of wiping the cart into a flash.
    * Serve leftover study crops so catalog cards match their objects
    CSS zoom left every individual card on the center floppy. Crop the
    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
